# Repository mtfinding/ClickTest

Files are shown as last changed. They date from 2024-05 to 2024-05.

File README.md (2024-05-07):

# Automated Continuity Testing Device

## Overview

This repository contains the finalized source-code and hardware design documents of an automated hardware-tester. The projects was created as part of bachelor-thesis and is specifically designed for the Nucleo L432KC development board in combination with a propriatory harwdare expander used at my uni FHTW)  
## Features

- **Automated Continuity Testing**: The device automates the continuity testing process, reducing manual effort and increasing efficiency.
- **Terminal Interface**: A 115200baud UART terminal is available to visulaize test-results and select from certain testing-options.
- **Quick-Test Button**: A physical button that can be mapped to various test-actions via terminal commands.

## System overview

The system consists of a single PCBA project which can be broken apart in all necessary components with only little manual THT soldering required.
The main components are outlined in the image below.

hw_overview

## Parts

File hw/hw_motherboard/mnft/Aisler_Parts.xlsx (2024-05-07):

RefDes | Required MPN | MFR | Footprint | Comment
C101, C201, C301, C302, C401, C601, C603 | C0603C105M3PACTU | KEMET | 0603
C102, C202, C303, C304, C402, C501, C502, C602, C604 | 0603F104Z500CT | WALSIN | 0603
D501, D502, D503, D504 | 1N4148WS | SMC Diode Solutions | SOD323
D505 | 150060RS75000 | Wurth Electronics | 0603
D506, D507, D508 | 150060GS75000 | Wurth Electronics | 0603
R101, R201, R301, R302, R401, R501, R505, R507, R515, R601, R624 | RK73H1JRTTD1002F | KOA | 0603
R416, R417, R418, R419, R511, R512, R513, R514, R625, R626, R627, R628, R629, R630, R631, R632 | 0R Resistor - USE SMART MATCH | - | 0603
R102, R103, R104, R105, R106, R107, R108, R109, R110, R111, R112, R113, R114, R115, R116, R117, R202, R203, R204, R205, R206, R207, R208, R209, R210, R211, R212, R213, R214, R215, R216, R217, R303, R304, R305, R306, R307, R308, R309, R310, R311, R312, R313, R314, R315, R316, R317, R318, R319, R320, R321, R322, R323, R324, R325, R326, R327, R328, R329, R330, R331, R332, R402, R403, R404, R405, R406, R407, R408, R409, R410, R411, R412, R413, R414, R415, R602, R603, R604, R605, R606, R607, R608, R609, R610, R611, R612, R613, R615, R616, R617, R618, R619, R620, R621, R622, R623 | RK73B1ETTP221J | KOA | 0402 | 220 ohm used instead of 200 ohm due to availability
R502, R503, R504, R506 | RK73B1JTTD222J | KOA | 0603
R508, R509, R510, R516, R517 | RK73H1JRTTD1001F | KOA | 0603
U101, U201, U301, U302, U401, U601, U602 | TCA9555PWR | Texas Instruments | TSSOP-24
Set all other positions to „Exclude“

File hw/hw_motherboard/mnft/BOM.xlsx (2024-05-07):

Comment | Designator | Footprint | JLCPCB Part #（optional）
C_0603_100n | C102,C202,C303,C304,C402,C501,C502,C602,C604 | C_0603_1608Metric | C14663
C_0603_1u | C101,C201,C301,C302,C401,C601,C603 | C_0603_1608Metric | C15849
1N4148WS | D501,D502,D503,D504 | D_SOD-323F | C2128
LED_Green | D506,D507,D508 | LED_0603_1608Metric | C72043
LED_Red | D505 | LED_0603_1608Metric | C2286
SD05C.TCT | D101,D102,D103,D104,D105,D106,D107,D108,D109,D110,D111,D112,D113,D114,D115,D116,D201,D202,D203,D204,D205,D206,D207,D208,D209,D210,D211,D212,D213,D214,D215,D216,D301,D302,D303,D304,D305,D306,D307,D308,D309,D310,D311,D312,D313,D314,D315,D316,D317,D318,D319,D320,D321,D322,D323,D324,D325,D326,D327,D328,D329,D330,D401,D402,D403,D404,D405,D406,D407,D408,D409,D410,D411,D412,D413,D414,D601,D602,D603,D604,D605,D606,D607,D608,D609,D610,D611,D612,D613,D614,D615,D616,D617,D618,D619,D620 | D_SOD-323_HandSoldering | C85200
0R | R416,R417,R418,R419,R511,R512,R513,R514,R625,R626,R627,R628,R629,R630,R631,R632 | R_0603_1608Metric_Pad0.98x0.95mm_HandSolder | C21189
0R_DNI | R614,R633 | R_0603_1608Metric_Pad0.98x0.95mm_HandSolder | C21189
R_0402_200 | R102,R103,R104,R105,R106,R107,R108,R109,R110,R111,R112,R113,R114,R115,R116,R117,R202,R203,R204,R205,R206,R207,R208,R209,R210,R211,R212,R213,R214,R215,R216,R217,R303,R304,R305,R306,R307,R308,R309,R310,R311,R312,R313,R314,R315,R316,R317,R318,R319,R320,R321,R322,R323,R324,R325,R326,R327,R328,R329,R330,R331,R332,R402,R403,R404,R405,R406,R407,R408,R409,R410,R411,R412,R413,R414,R415,R602,R603,R604,R605,R606,R607,R608,R609,R610,R611,R612,R613,R615,R616,R617,R618,R619,R620,R621,R622,R623 | R_0402_1005Metric | C25087
R_0603_10k | R101,R201,R301,R302,R401,R501,R505,R507,R515,R601,R624 | R_0603_1608Metric | C25804
R_0603_1k | R508,R509,R510,R516,R517 | R_0603_1608Metric | C21190
R_0603_2.2k | R502,R503,R504,R506 | R_0603_1608Metric | C4190
TCA9555PWR | U101, U201, U301, U302, U401, U601, U602 | TSSOP-24_4.4x7.8mm_P0.65mm | C465732

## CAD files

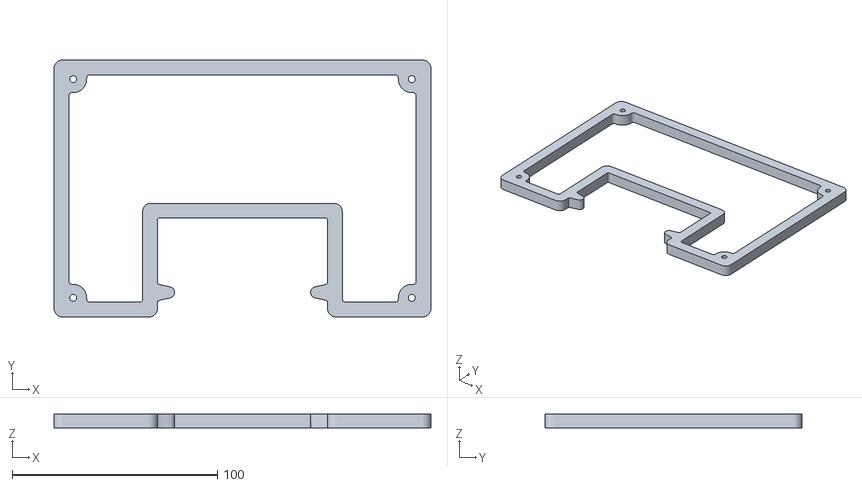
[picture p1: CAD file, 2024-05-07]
hw/mount/bac_hw_motherboard_mount_v1.stl
183.8 x 125.4 x 7.00

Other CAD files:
hw/mount/bac_hw_motherboard_mount_v1.f3d

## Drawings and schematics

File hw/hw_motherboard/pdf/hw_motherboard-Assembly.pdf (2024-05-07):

+ ERROR ⁺ | +

5V +

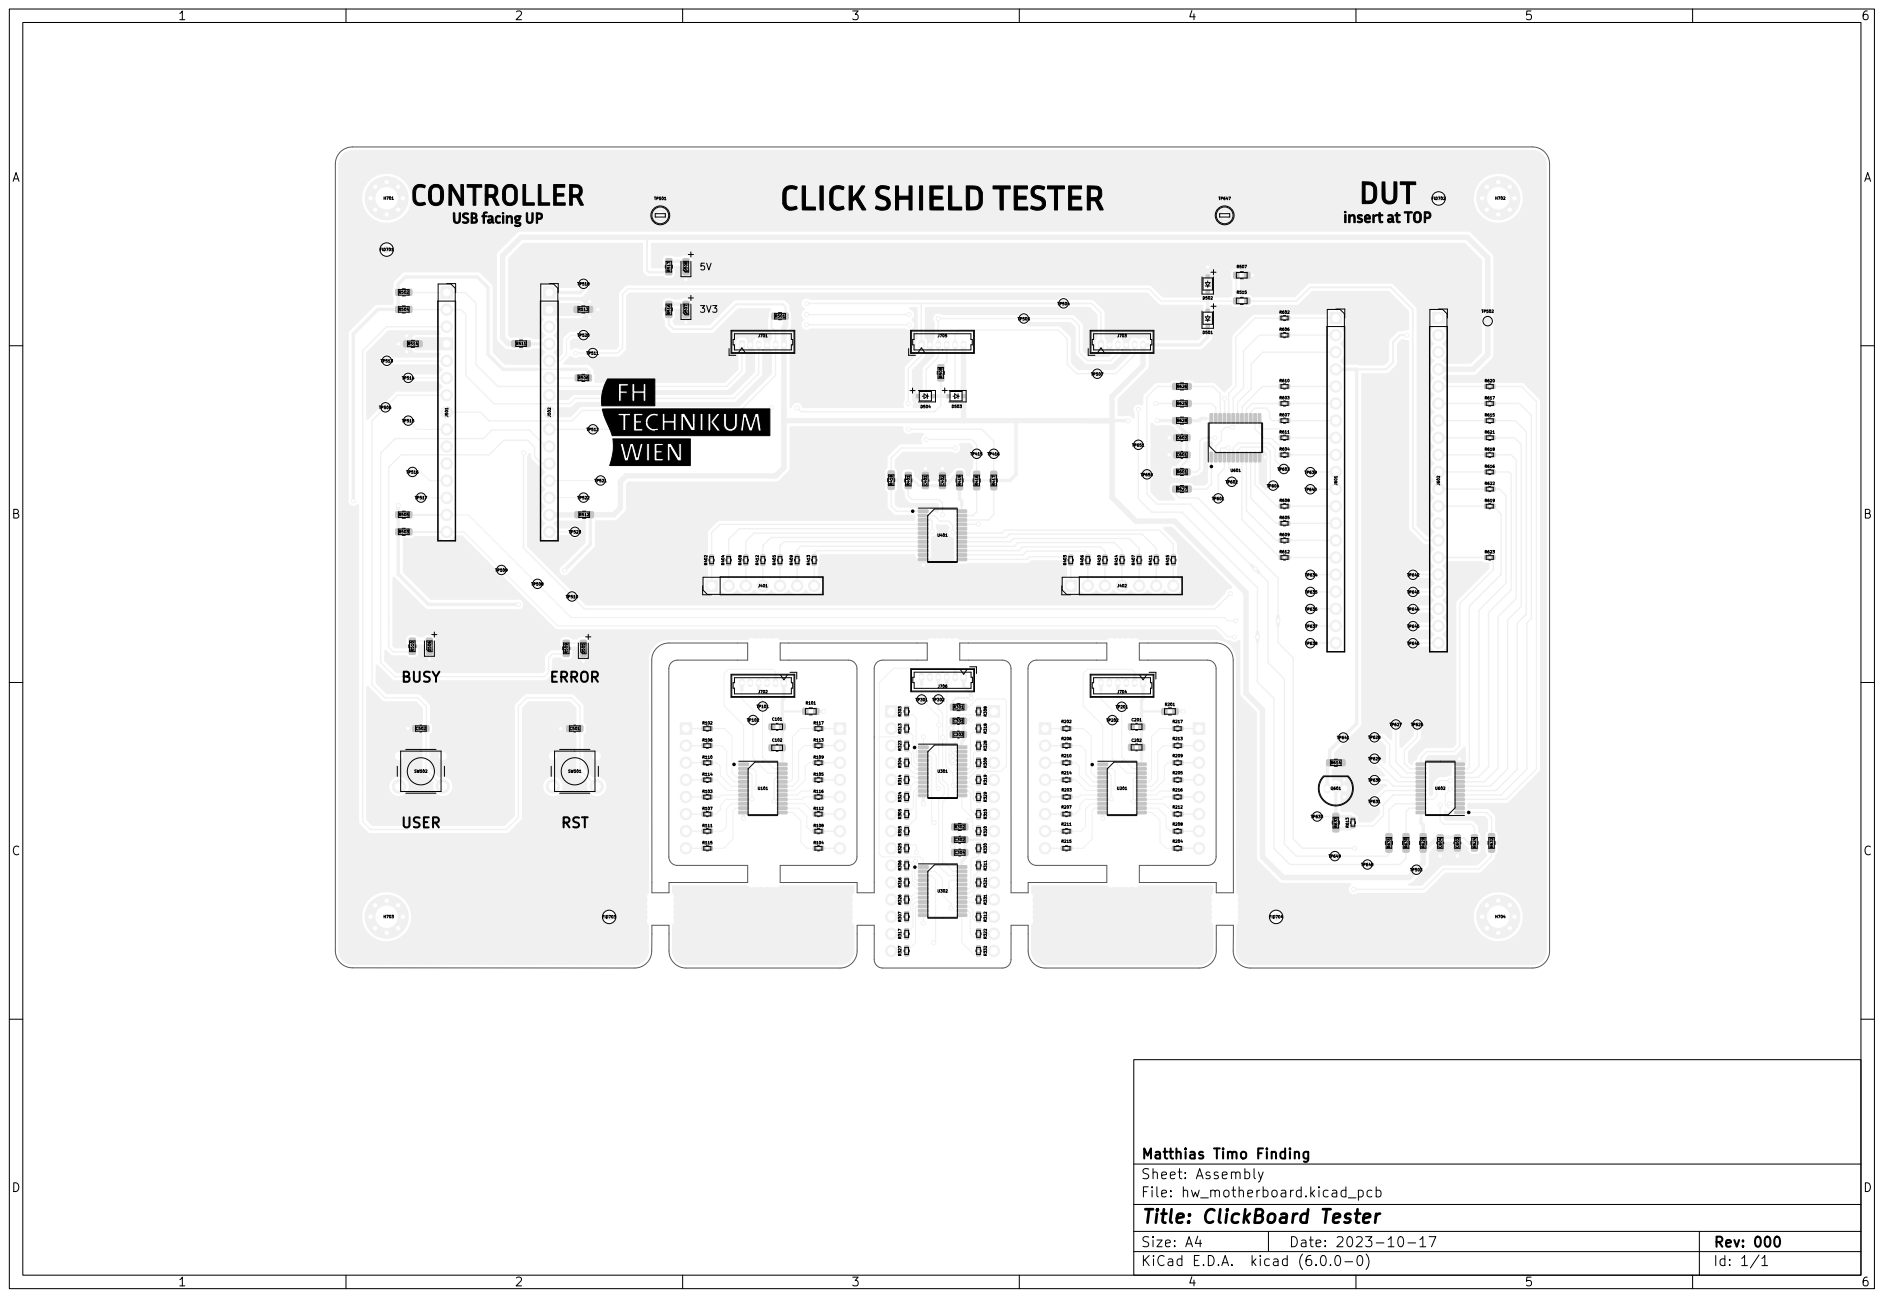
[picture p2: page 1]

Sheet: Assembly
File: hw_motherboard.kicad_pcb
Id: 1/1 Title: ClickBoard Tester

1 | 2 | 3 | 4 | 5 | 6

A

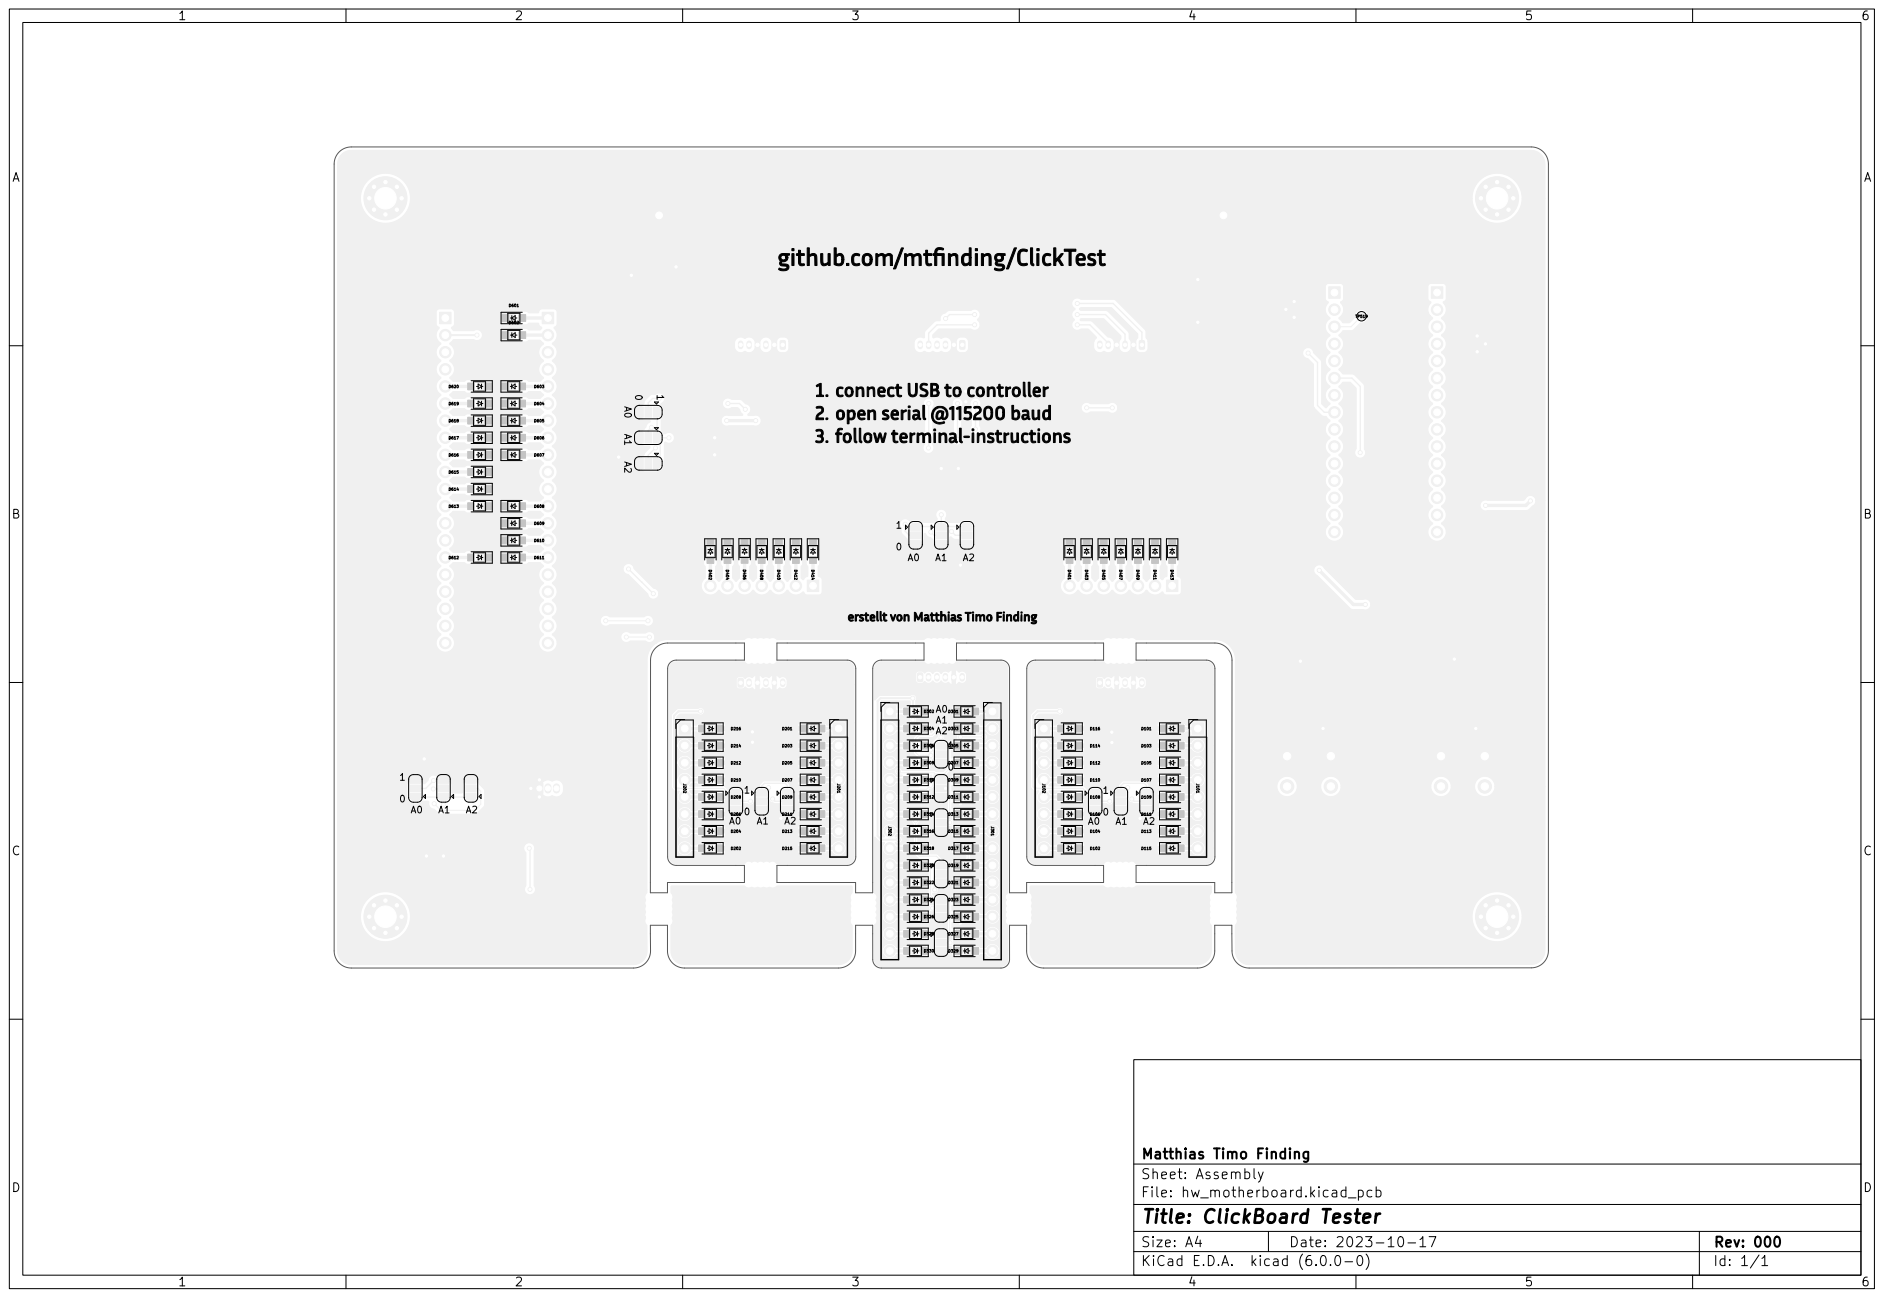
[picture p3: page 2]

Matthias Timo Finding
Sheet: Assembly
File: hw_motherboard.kicad_pcb
Id: 1/1 Title: ClickBoard Tester

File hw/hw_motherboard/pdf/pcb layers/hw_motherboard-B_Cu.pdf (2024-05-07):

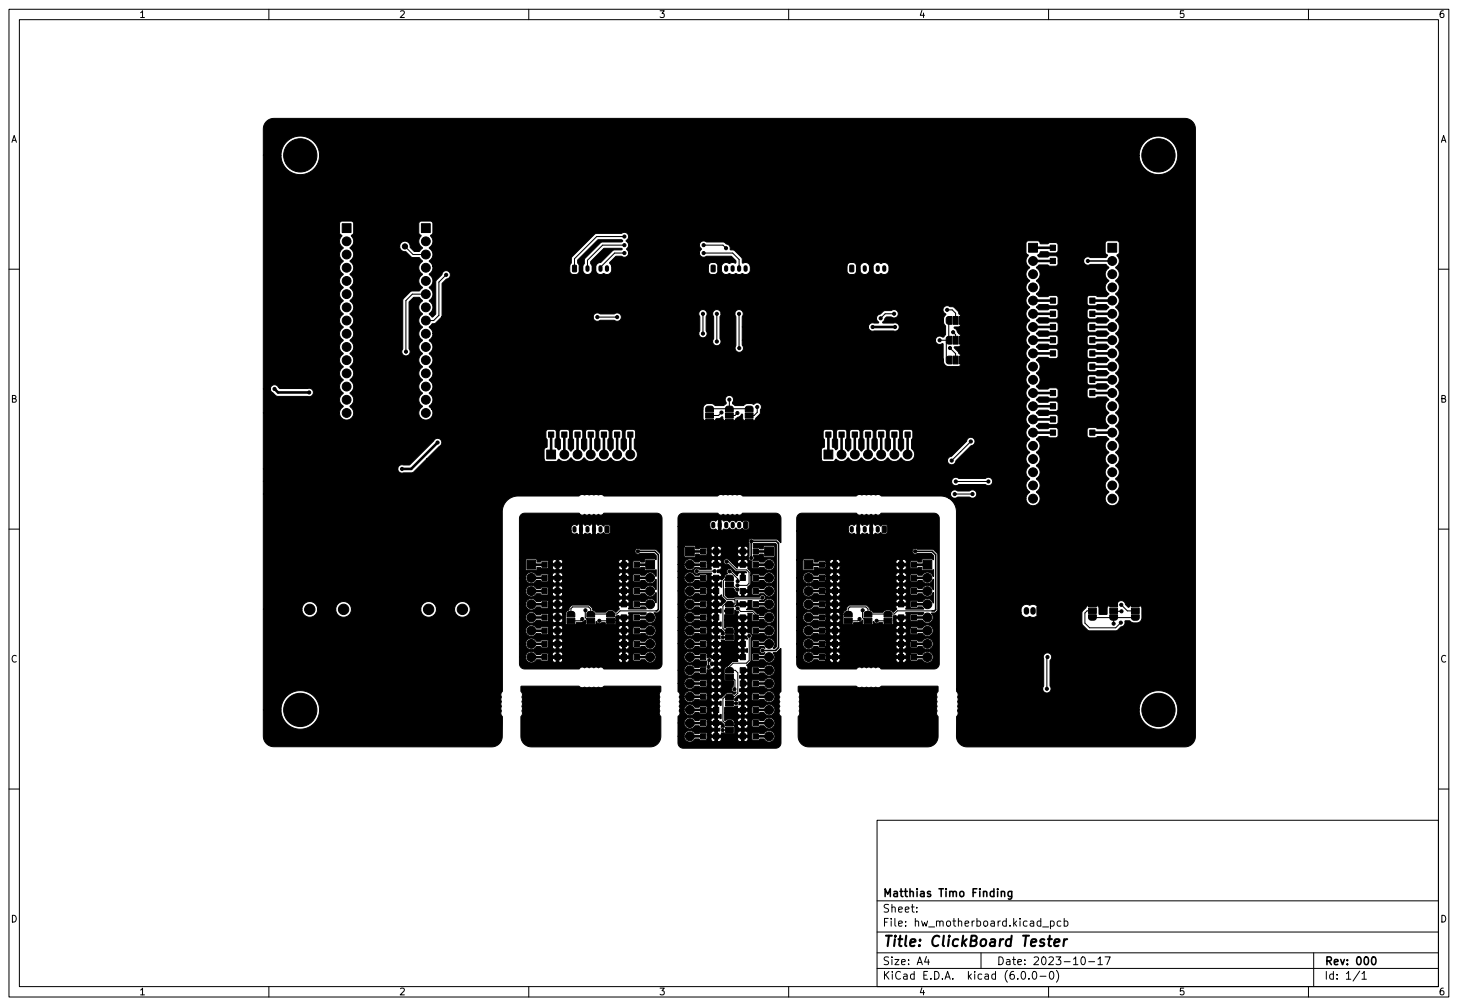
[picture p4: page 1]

File: hw_motherboard.kicad_pcb Sheet: Matthias Timo Finding

Id: 1/1 Title: ClickBoard Tester

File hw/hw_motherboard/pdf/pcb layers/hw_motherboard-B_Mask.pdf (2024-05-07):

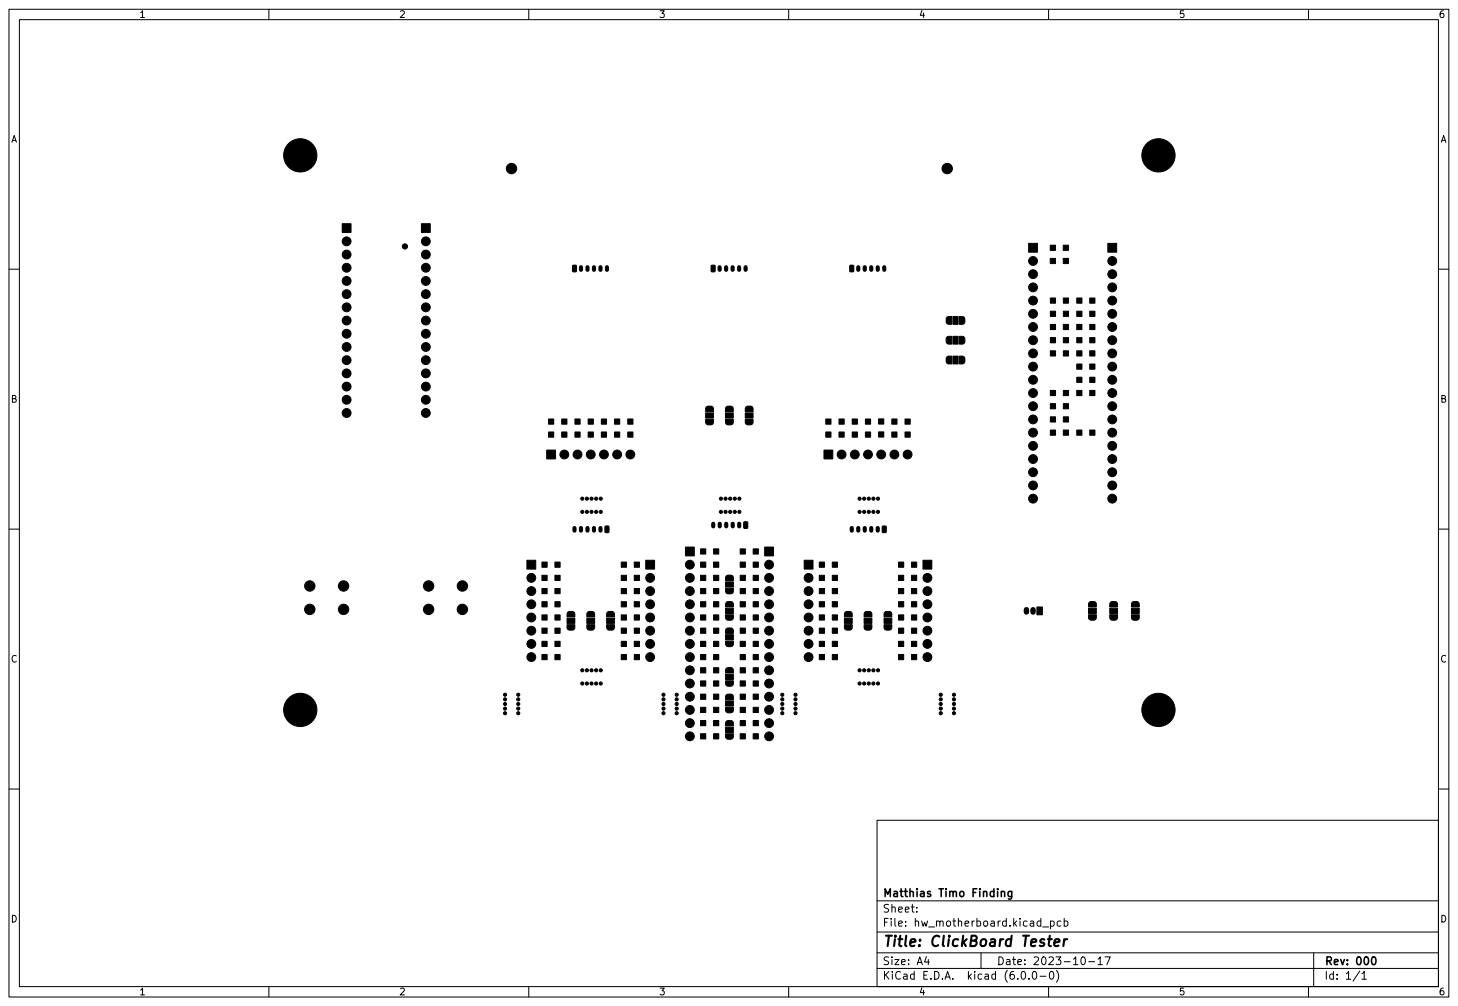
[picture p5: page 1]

File: hw_motherboard.kicad_pcb Sheet: Matthias Timo Finding

Id: 1/1 Title: ClickBoard Tester

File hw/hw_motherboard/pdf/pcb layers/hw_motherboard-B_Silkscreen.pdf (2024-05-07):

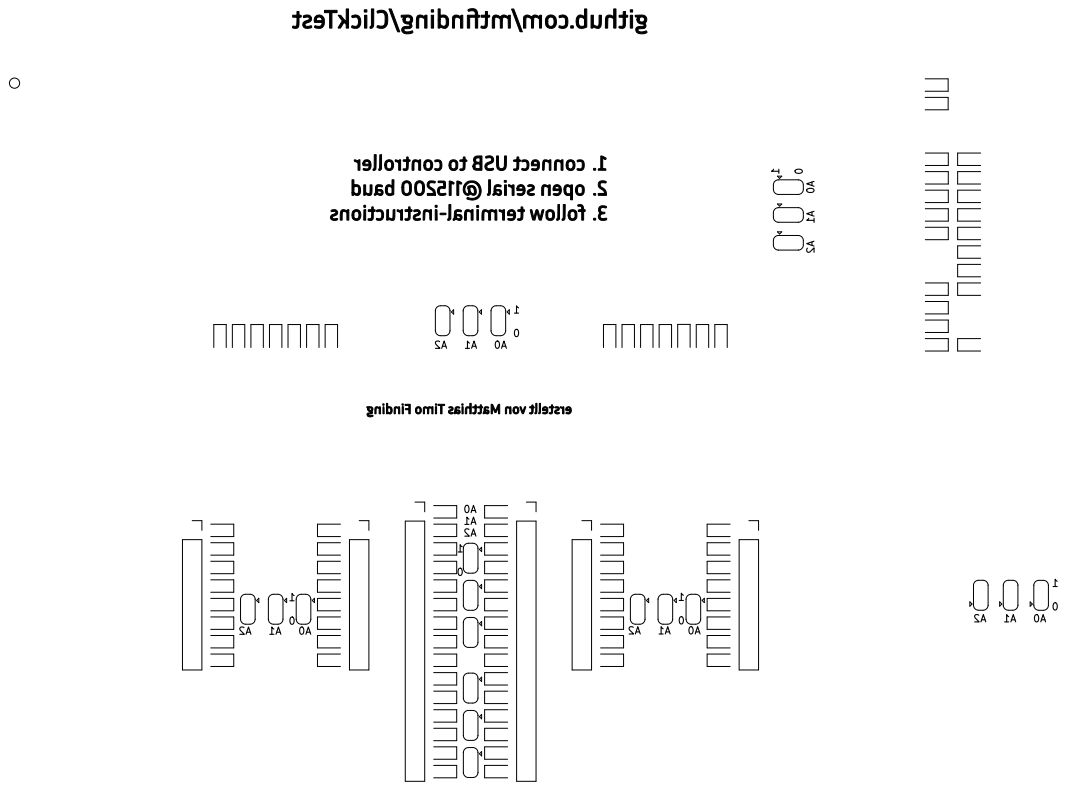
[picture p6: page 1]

File: hw_motherboard.kicad_pcb Sheet: Matthias Timo Finding

Id: 1/1 Title: ClickBoard Tester

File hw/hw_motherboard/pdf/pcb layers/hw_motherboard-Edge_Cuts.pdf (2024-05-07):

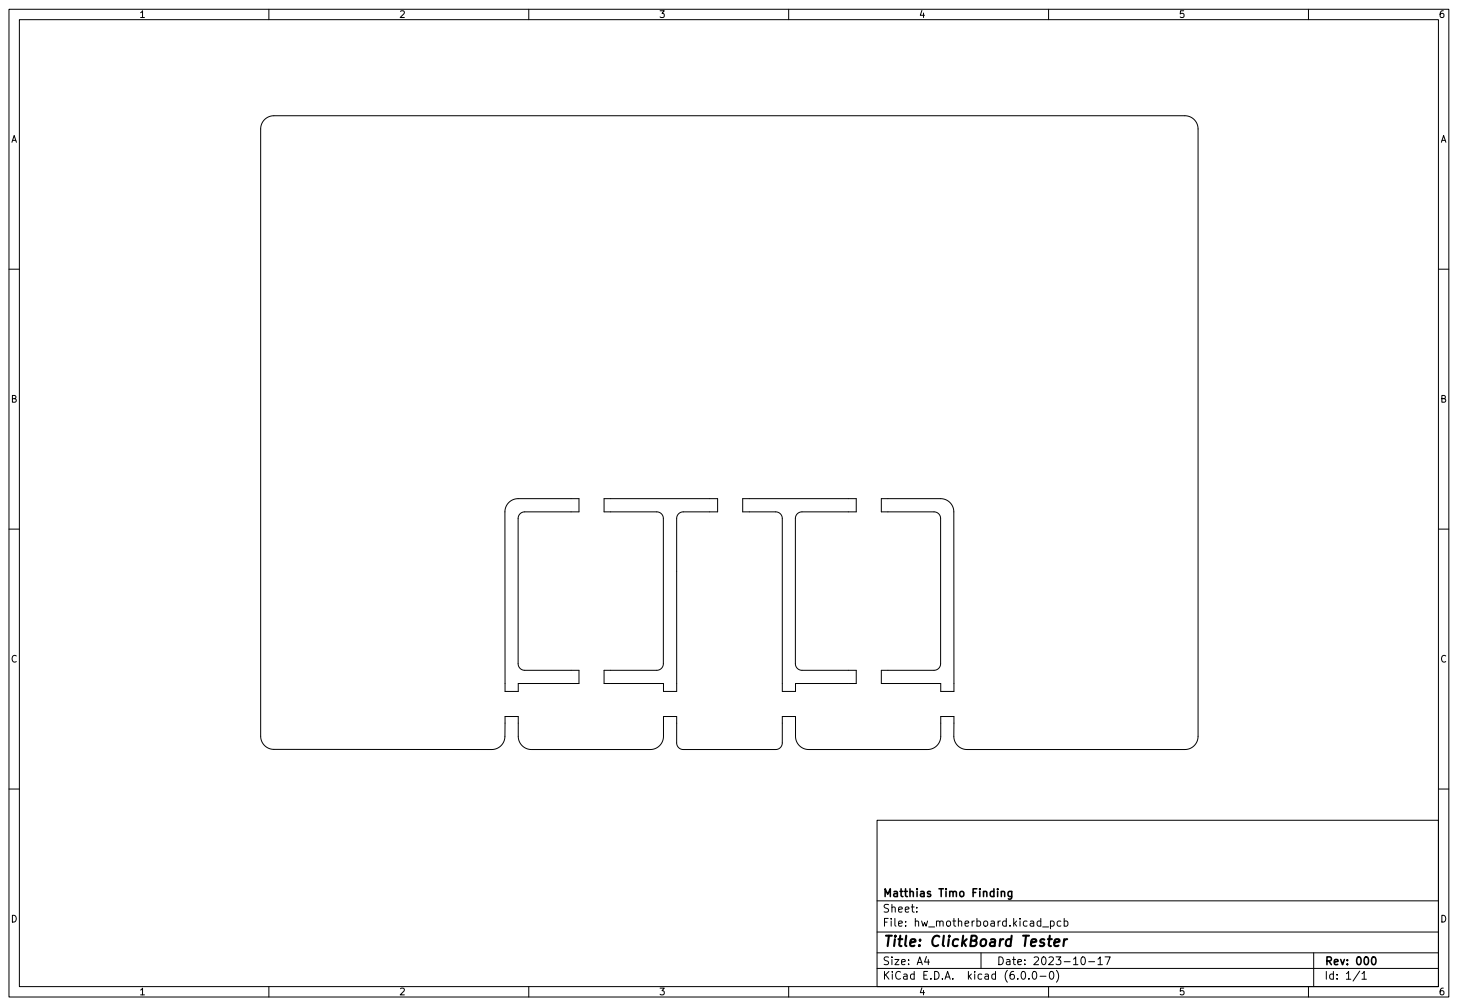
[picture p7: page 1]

File: hw_motherboard.kicad_pcb Sheet: Matthias Timo Finding

Id: 1/1 Title: ClickBoard Tester

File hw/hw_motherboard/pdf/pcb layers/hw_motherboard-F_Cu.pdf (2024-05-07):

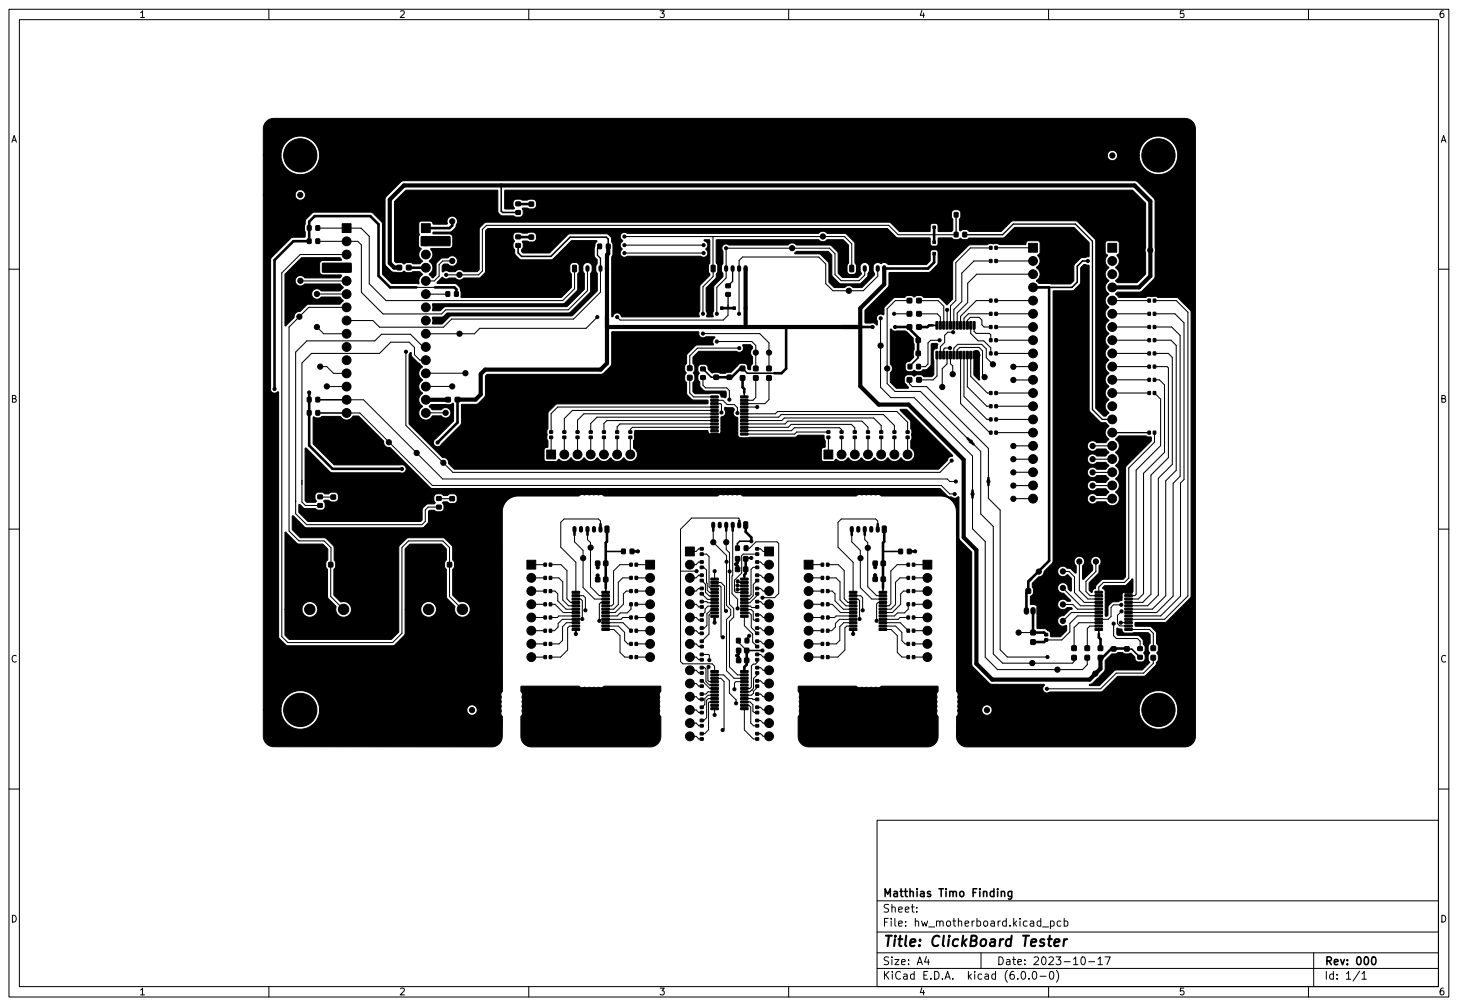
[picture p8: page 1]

File: hw_motherboard.kicad_pcb Sheet: Matthias Timo Finding

Id: 1/1 Title: ClickBoard Tester

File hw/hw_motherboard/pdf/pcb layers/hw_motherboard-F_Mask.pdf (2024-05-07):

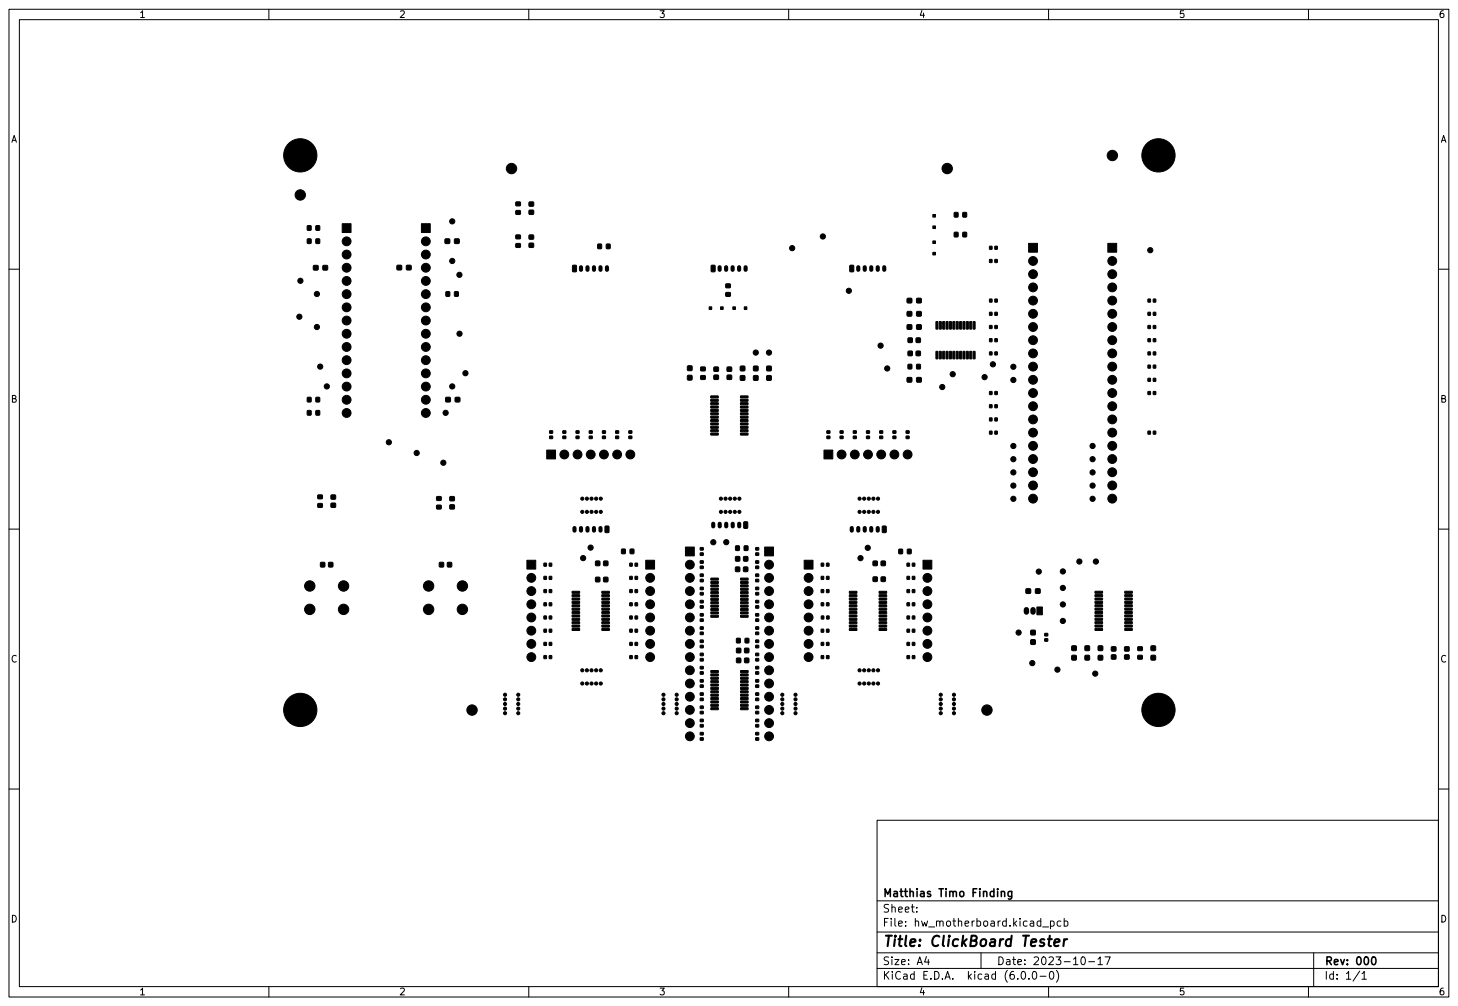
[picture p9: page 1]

File: hw_motherboard.kicad_pcb Sheet: Matthias Timo Finding

Id: 1/1 Title: ClickBoard Tester

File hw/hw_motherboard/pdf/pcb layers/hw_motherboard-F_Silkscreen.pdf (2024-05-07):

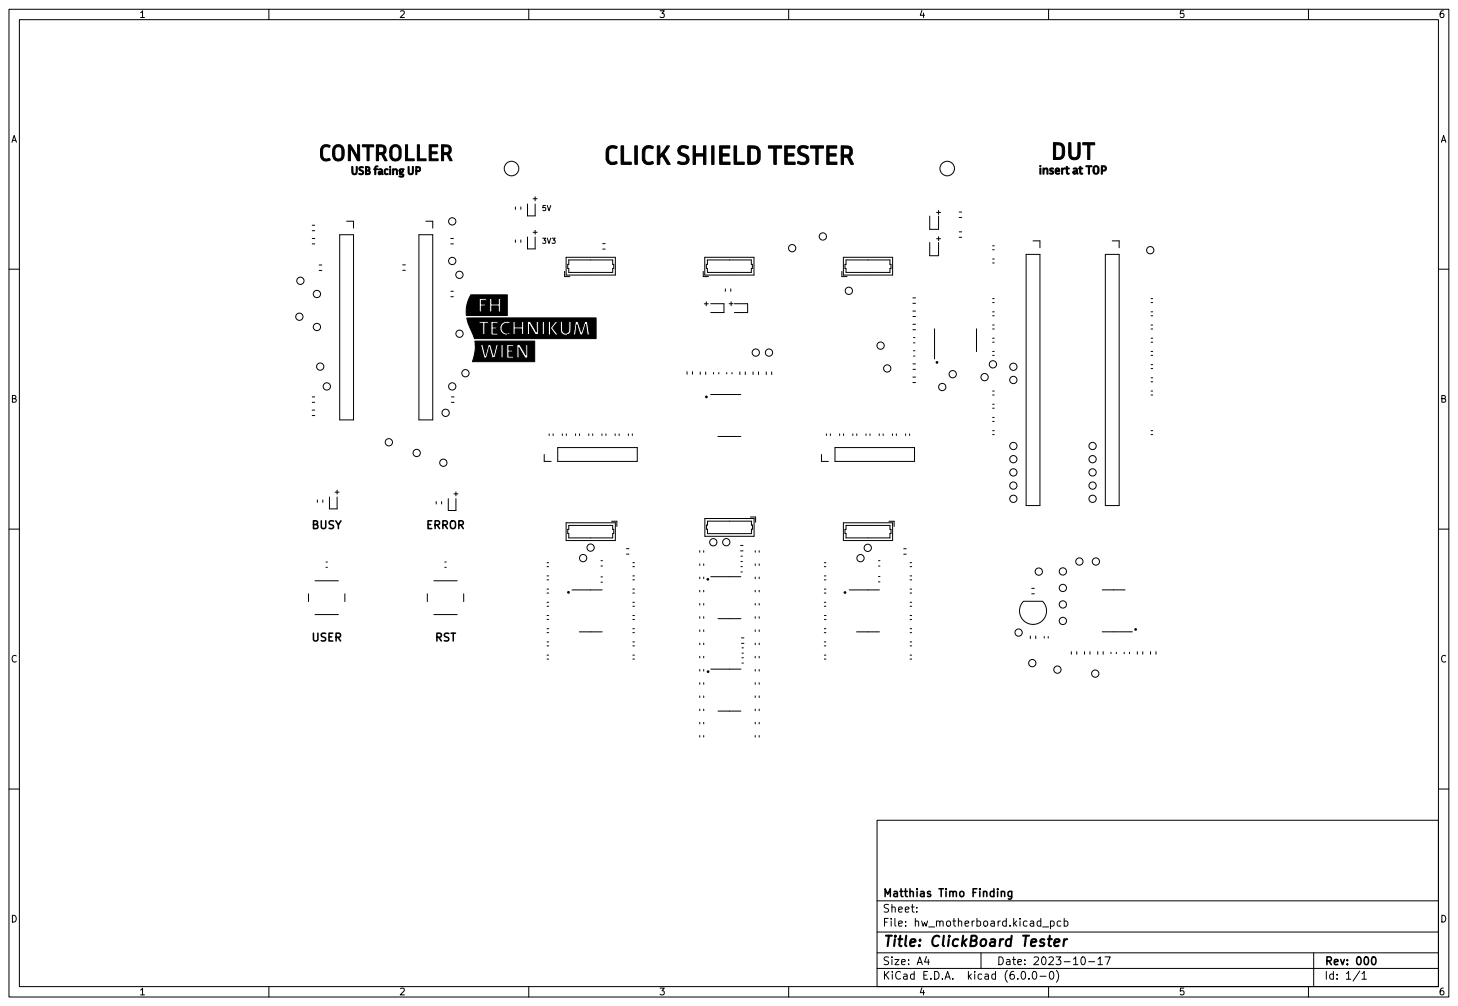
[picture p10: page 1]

File: hw_motherboard.kicad_pcb Sheet: Matthias Timo Finding

Id: 1/1 Title: ClickBoard Tester

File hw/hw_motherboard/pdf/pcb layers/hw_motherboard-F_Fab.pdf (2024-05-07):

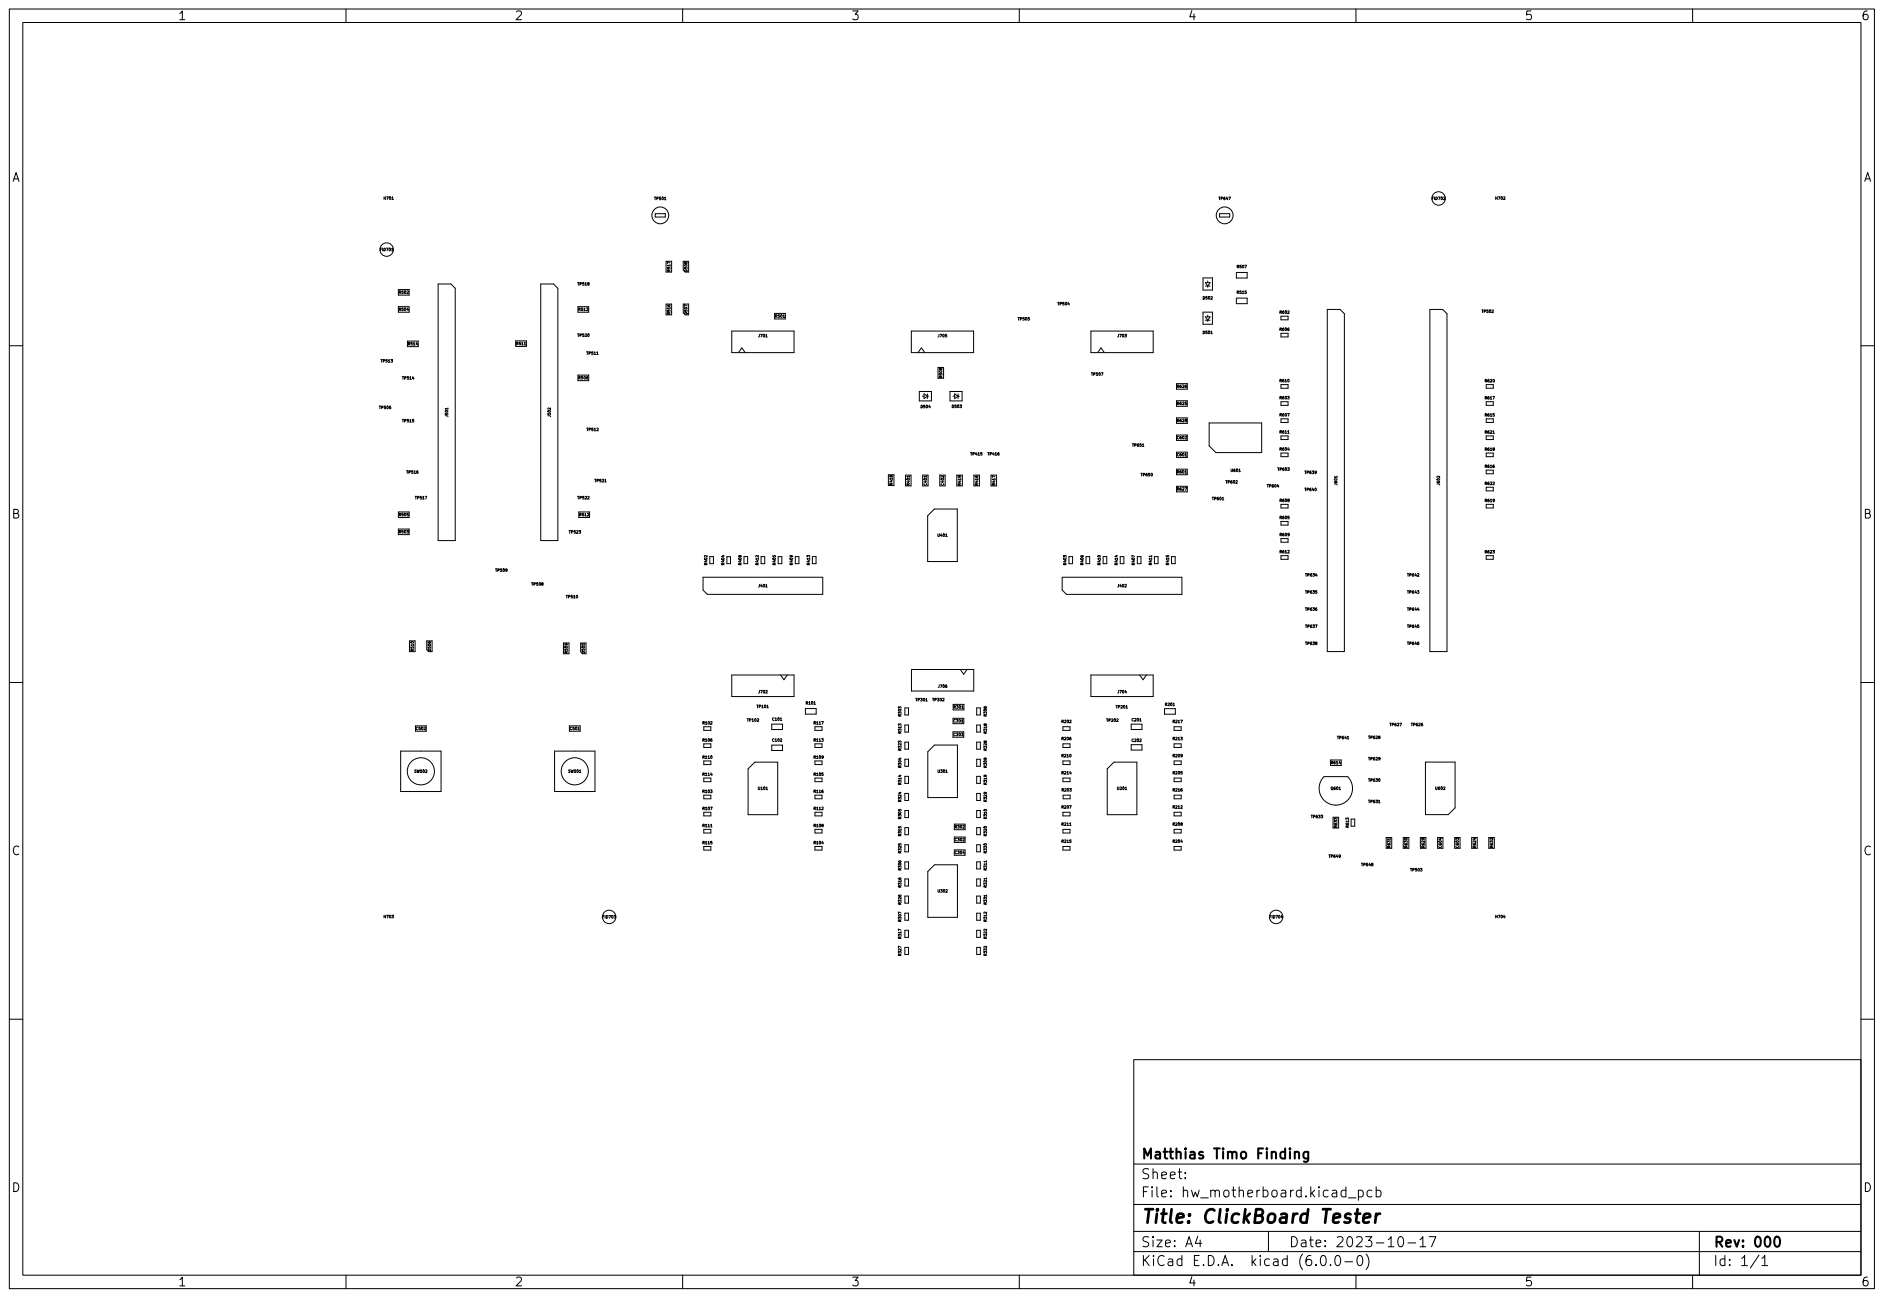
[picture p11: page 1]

Id: 1/1 Title: ClickBoard Tester

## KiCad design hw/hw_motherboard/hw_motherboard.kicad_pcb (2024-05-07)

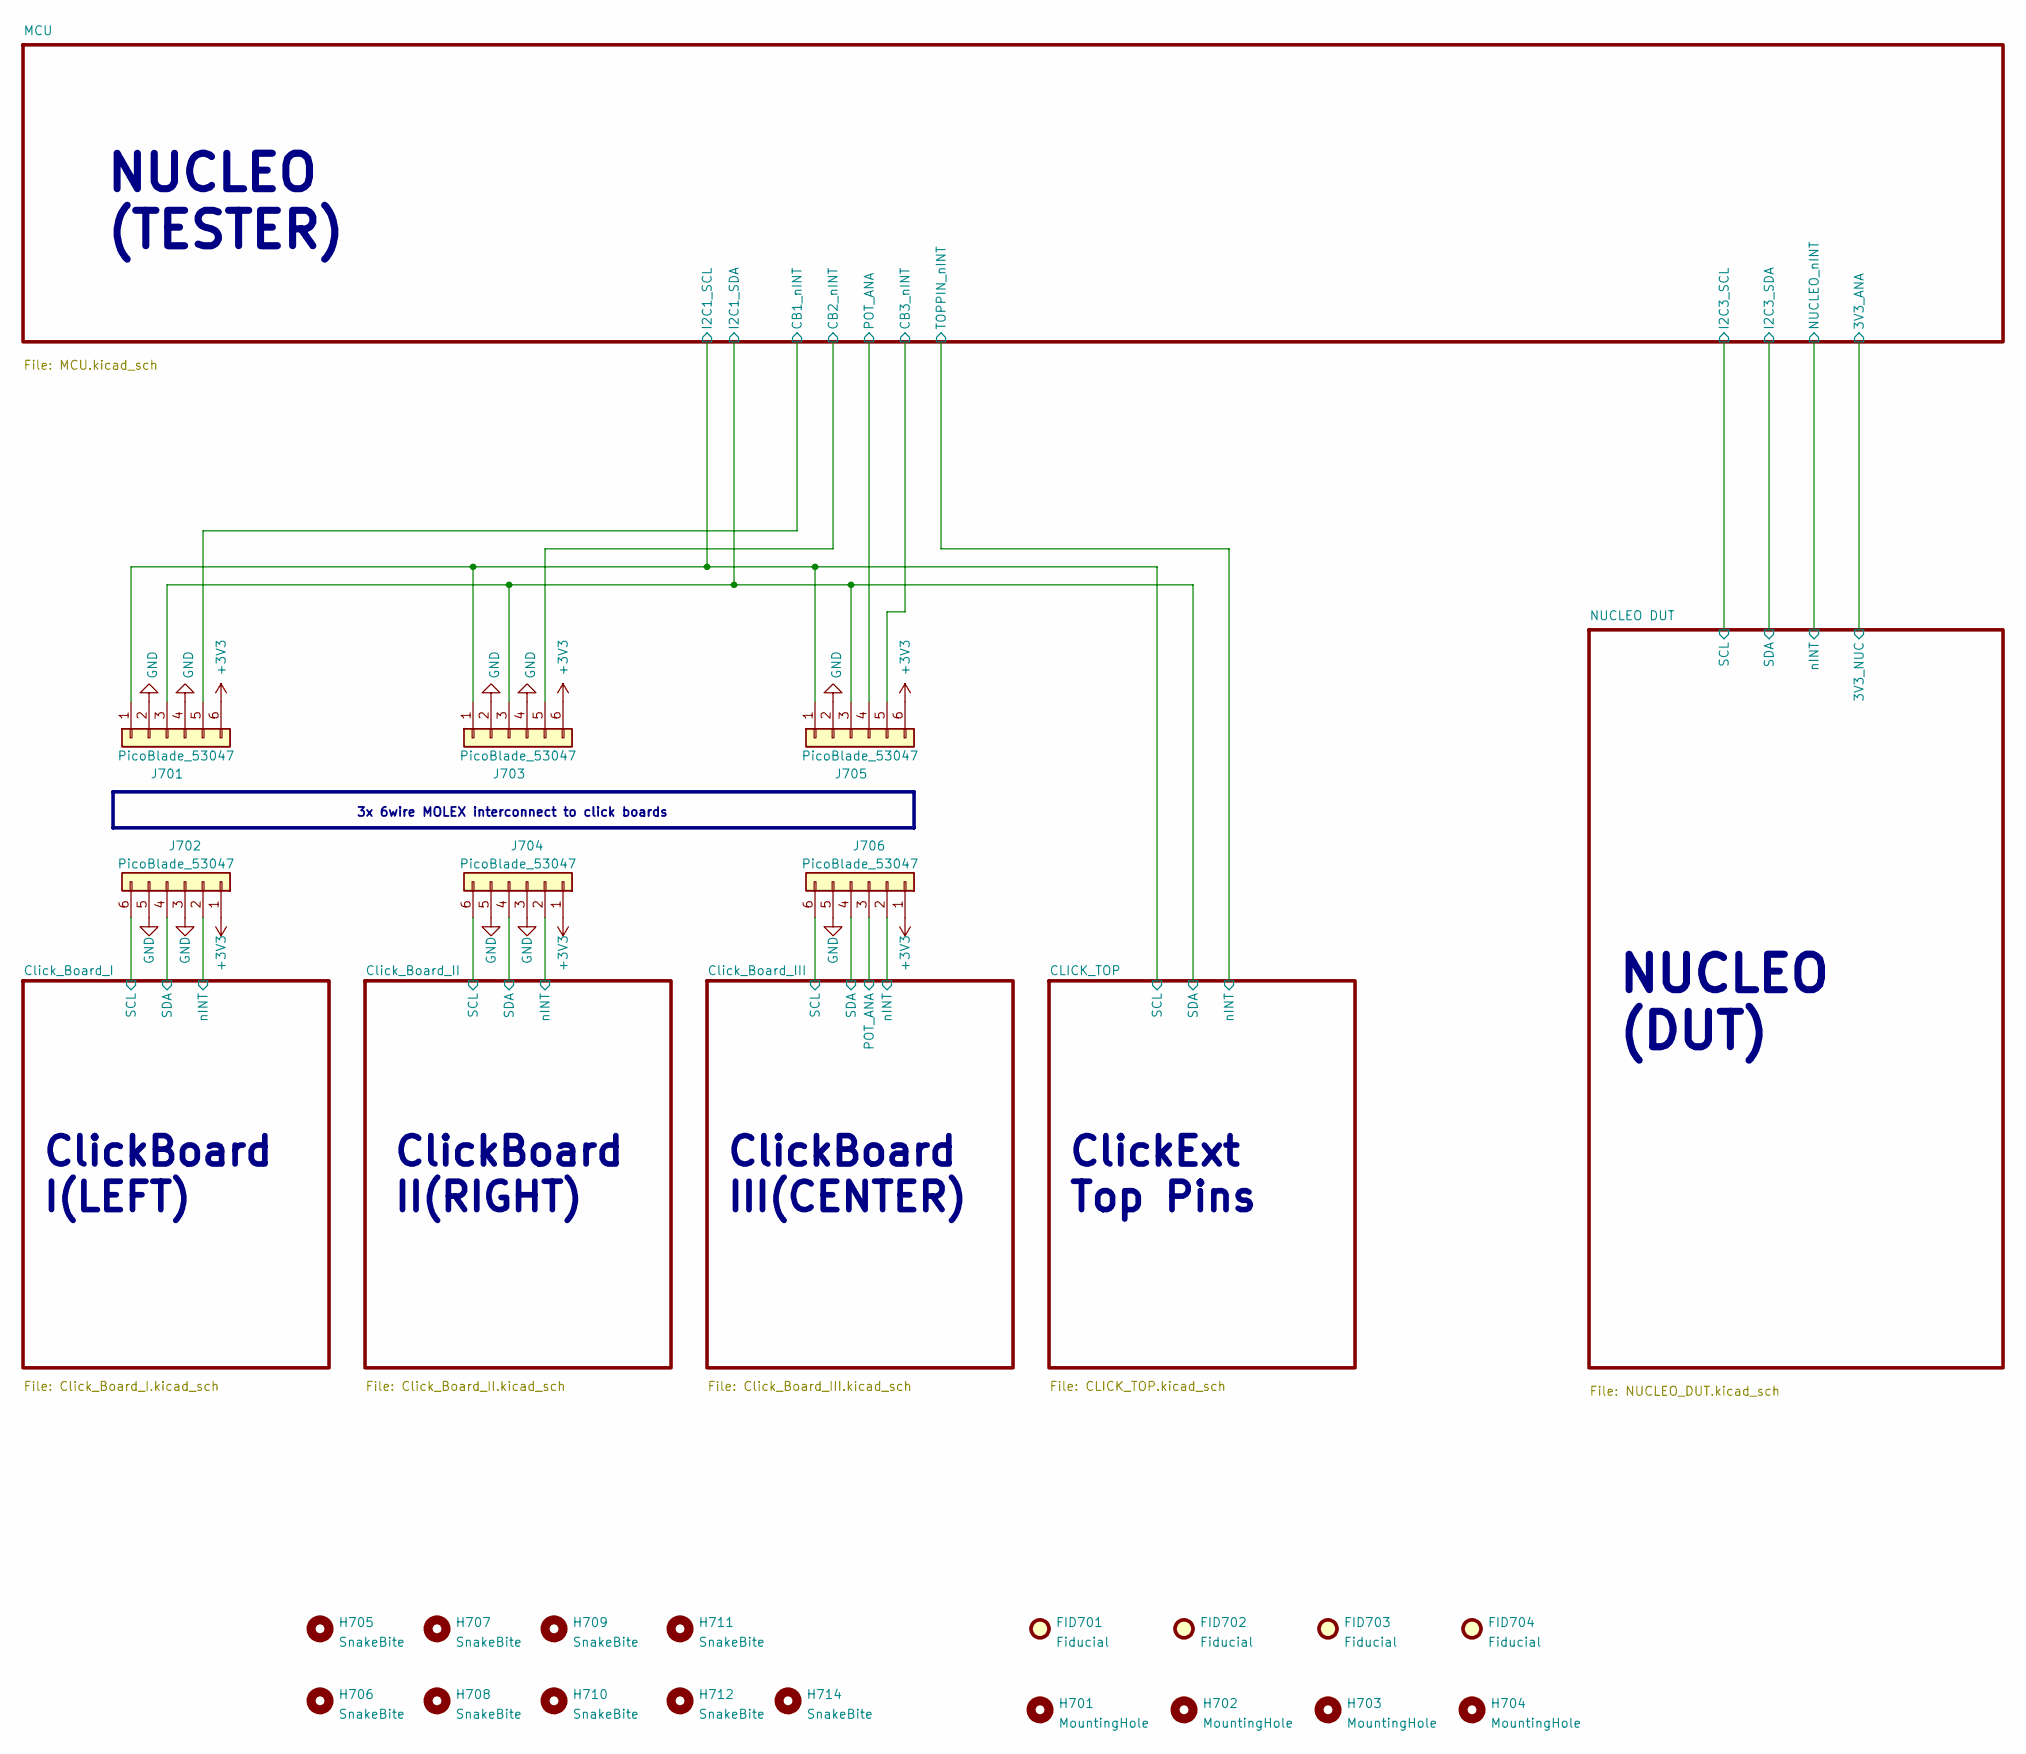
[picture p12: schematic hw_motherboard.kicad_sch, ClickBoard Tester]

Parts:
FID701, FID702, FID703, FID704: Fiducial; Fiducial_1mm_Mask2mm
H701, H702, H703, H704: MountingHole; MountingHole_3.2mm_M3_Pad_Via
H705, H706, H707, H708, H709, H710, H711, H712, H714: SnakeBite; JLC_SnakeBite_1.27mm
J701, J702, J703, J704, J705, J706: PicoBlade_53047; Molex_PicoBlade_53047-0610_1x06_P1.25mm_Vertical

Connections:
+3V3: J701.6, J702.1, J703.6, J704.1, J705.6, J706.1; also elsewhere on the board
/Click_Board_I/SCL: J702.6; also elsewhere on the board
/Click_Board_I/SDA: J702.4; also elsewhere on the board
/Click_Board_I/nINT: J702.2; also elsewhere on the board
/Click_Board_II/SCL: J704.6; also elsewhere on the board
/Click_Board_II/SDA: J704.4; also elsewhere on the board
/Click_Board_II/nINT: J704.2; also elsewhere on the board
/Click_Board_III/POT_ANA: J706.3; also elsewhere on the board
/Click_Board_III/SCL: J706.6; also elsewhere on the board
/Click_Board_III/SDA: J706.4; also elsewhere on the board
/Click_Board_III/nINT: J706.2; also elsewhere on the board
/MCU/MCU_PA9: J701.1, J703.1, J705.1; also elsewhere on the board
/MCU/MCU_PA10: J701.3, J703.3, J705.3; also elsewhere on the board
/MCU/MCU_PB6: J701.5, J703.5, J705.5; also elsewhere on the board
/MCU/POT_ANA: J705.4; also elsewhere on the board
GND: J701.2, J701.4, J702.3, J702.5, J703.2, J703.4, J704.3, J704.5, J705.2, J706.5; also elsewhere on the board

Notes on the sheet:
3x 6wire MOLEX interconnect to click boards
NUCLEO (DUT)
ClickBoard I(LEFT)
ClickExt Top Pins
ClickBoard III(CENTER)
NUCLEO (TESTER)
ClickBoard II(RIGHT)

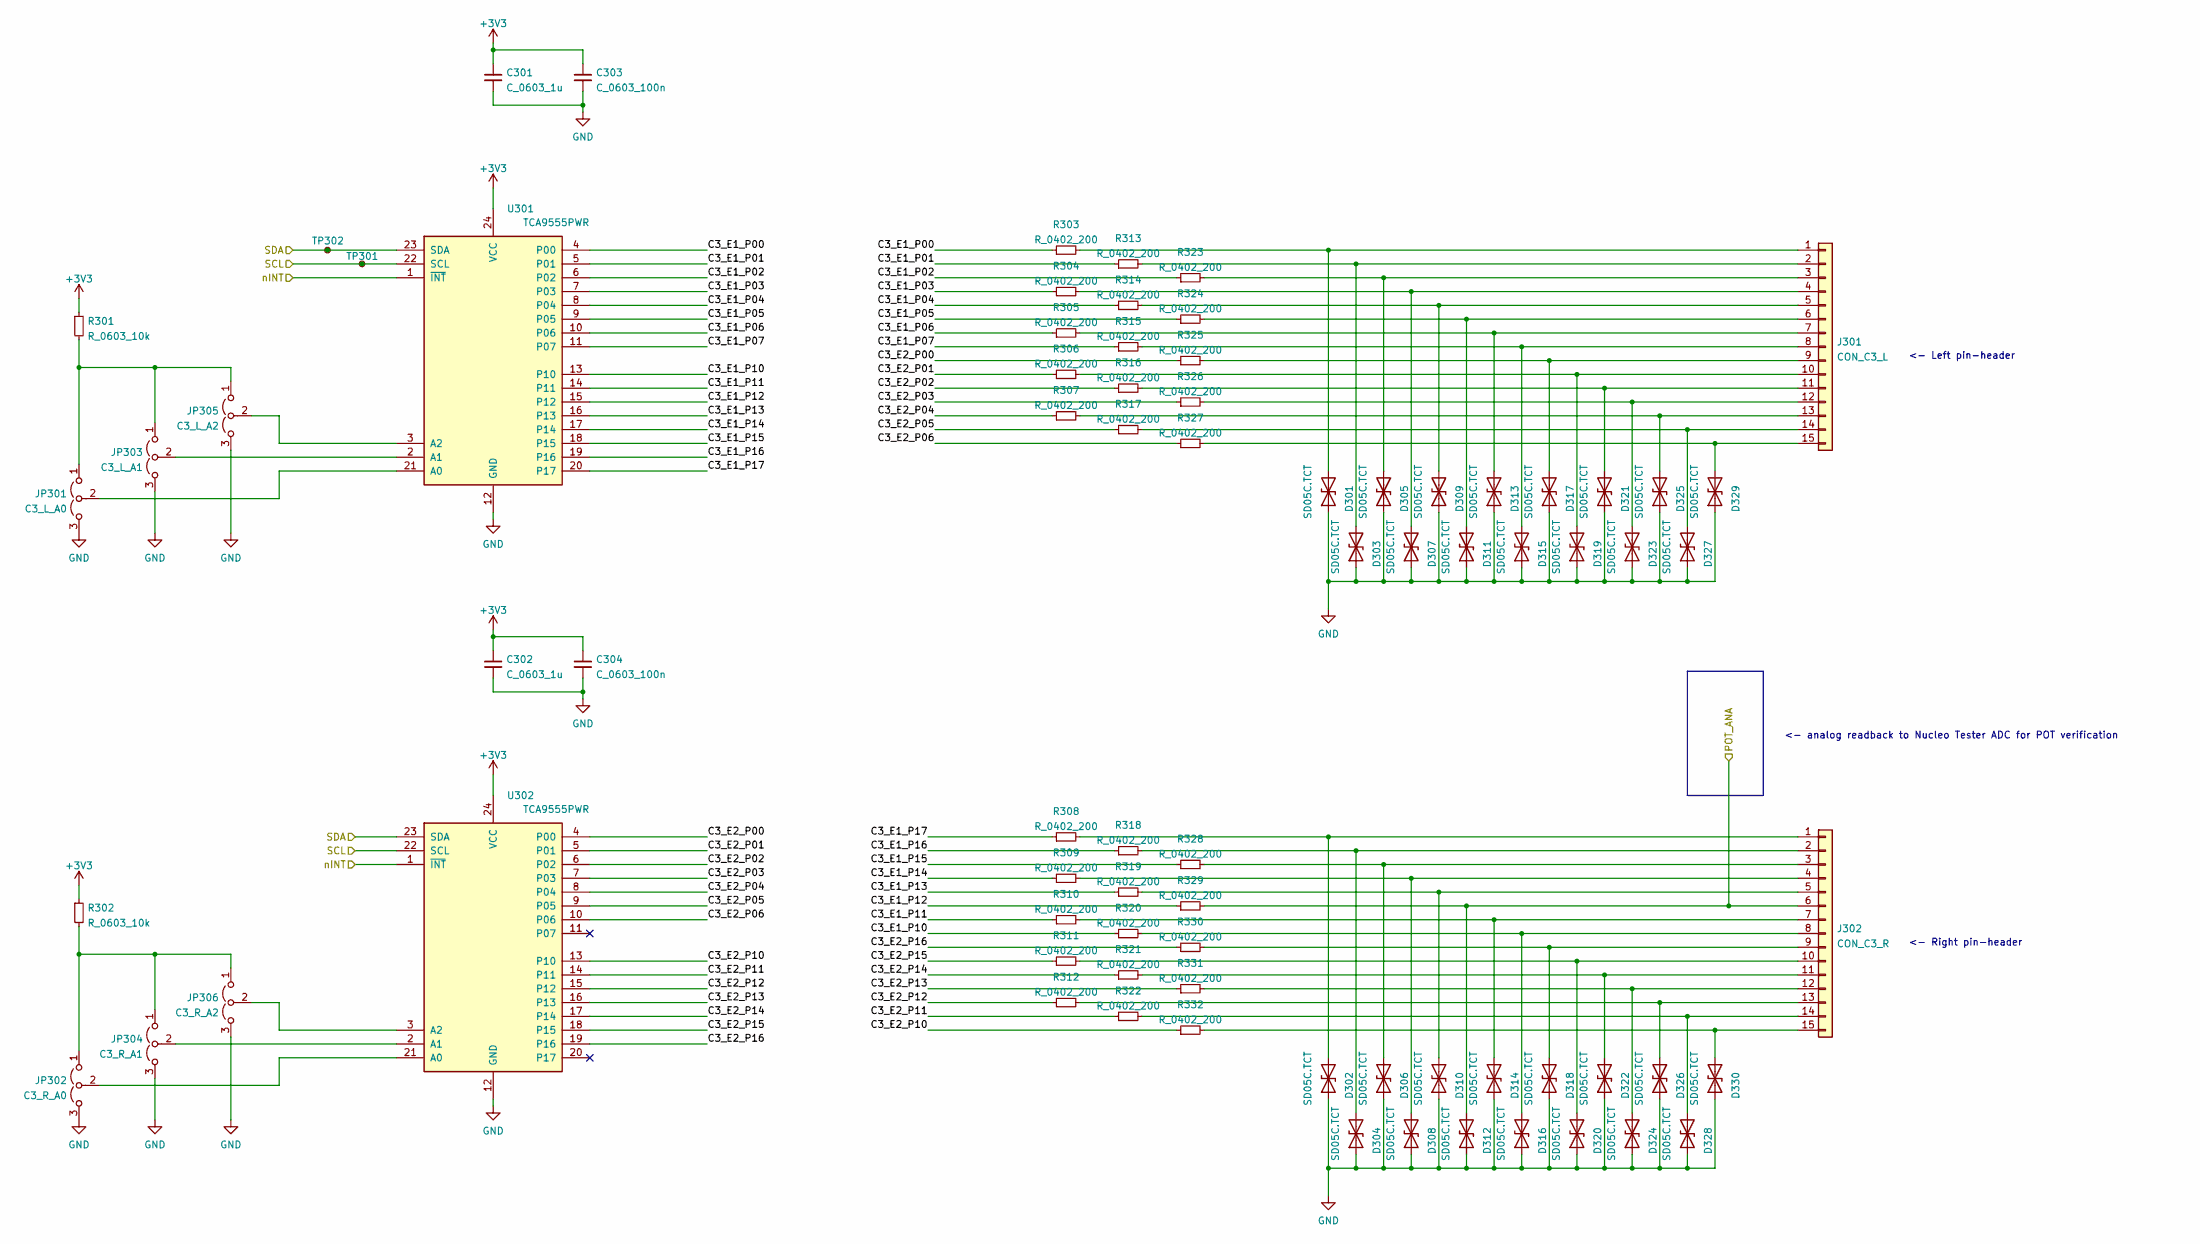
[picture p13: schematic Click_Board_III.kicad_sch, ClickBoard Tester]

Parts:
C301, C302: C_0603_1u; C_0603_1608Metric; LCSC Part # C15849
C303, C304: C_0603_100n; C_0603_1608Metric; LCSC Part # C14663
D301, D302, D303, D304, D305, D306, D307, D308, D309, D310, D311, D312, D313, D314, D315, D316, D317, D318, D319, D320, D321, D322, D323, D324, D325, D326, D327, D328, D329, D330: SD05C.TCT; D_SOD-323_HandSoldering; LCSC Part # C85200
J301: CON_C3_L; PinHeader_1x15_P2.54mm_Vertical
J302: CON_C3_R; PinHeader_1x15_P2.54mm_Vertical
JP301: C3_L_A0; SolderJumper-3_P1.3mm_Open_RoundedPad1.0x1.5mm
JP302: C3_R_A0; SolderJumper-3_P1.3mm_Open_RoundedPad1.0x1.5mm
JP303: C3_L_A1; SolderJumper-3_P1.3mm_Open_RoundedPad1.0x1.5mm
JP304: C3_R_A1; SolderJumper-3_P1.3mm_Open_RoundedPad1.0x1.5mm
JP305: C3_L_A2; SolderJumper-3_P1.3mm_Open_RoundedPad1.0x1.5mm
JP306: C3_R_A2; SolderJumper-3_P1.3mm_Open_RoundedPad1.0x1.5mm
R301, R302: R_0603_10k; R_0603_1608Metric; LCSC Part # C25804
R303, R304, R305, R306, R307, R308, R309, R310, R311, R312, R313, R314, R315, R316, R317, R318, R319, R320, R321, R322, R323, R324, R325, R326, R327, R328, R329, R330, R331, R332: R_0402_200; R_0402_1005Metric; LCSC Part # C25087
TP301, TP302: TestPoint_Small; TestPoint_Pad_D1.0mm
U301, U302: TCA9555PWR; TSSOP-24_4.4x7.8mm_P0.65mm

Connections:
+3V3: C301.1, C302.1, C303.1, C304.1, R301.1, R302.1, U301.24 (VCC), U302.24 (VCC); also elsewhere on the board
/Click_Board_III/C3_E1_P00: R303.1, U301.4 (P00)
/Click_Board_III/C3_E1_P01: R313.1, U301.5 (P01)
/Click_Board_III/C3_E1_P02: R323.1, U301.6 (P02)
/Click_Board_III/C3_E1_P03: R304.1, U301.7 (P03)
/Click_Board_III/C3_E1_P04: R314.1, U301.8 (P04)
/Click_Board_III/C3_E1_P05: R324.1, U301.9 (P05)
/Click_Board_III/C3_E1_P06: R305.1, U301.10 (P06)
/Click_Board_III/C3_E1_P07: R315.1, U301.11 (P07)
/Click_Board_III/C3_E1_P10: R320.1, U301.13 (P10)
/Click_Board_III/C3_E1_P11: R310.1, U301.14 (P11)
/Click_Board_III/C3_E1_P12: R329.1, U301.15 (P12)
/Click_Board_III/C3_E1_P13: R319.1, U301.16 (P13)
/Click_Board_III/C3_E1_P14: R309.1, U301.17 (P14)
/Click_Board_III/C3_E1_P15: R328.1, U301.18 (P15)
/Click_Board_III/C3_E1_P16: R318.1, U301.19 (P16)
/Click_Board_III/C3_E1_P17: R308.1, U301.20 (P17)
/Click_Board_III/C3_E2_P00: R325.1, U302.4 (P00)
/Click_Board_III/C3_E2_P01: R306.1, U302.5 (P01)
/Click_Board_III/C3_E2_P02: R316.1, U302.6 (P02)
/Click_Board_III/C3_E2_P03: R326.1, U302.7 (P03)
/Click_Board_III/C3_E2_P04: R307.1, U302.8 (P04)
/Click_Board_III/C3_E2_P05: R317.1, U302.9 (P05)
/Click_Board_III/C3_E2_P06: R327.1, U302.10 (P06)
/Click_Board_III/C3_E2_P10: R332.1, U302.13 (P10)
/Click_Board_III/C3_E2_P11: R322.1, U302.14 (P11)
/Click_Board_III/C3_E2_P12: R312.1, U302.15 (P12)
/Click_Board_III/C3_E2_P13: R331.1, U302.16 (P13)
/Click_Board_III/C3_E2_P14: R321.1, U302.17 (P14)
/Click_Board_III/C3_E2_P15: R311.1, U302.18 (P15)
/Click_Board_III/C3_E2_P16: R330.1, U302.19 (P16)
/Click_Board_III/POT_ANA: D312.2 (A2), J302.6, R329.2; also elsewhere on the board
/Click_Board_III/SCL: TP301.1, U301.22 (SCL), U302.22 (SCL); also elsewhere on the board
/Click_Board_III/SDA: TP302.1, U301.23 (SDA), U302.23 (SDA); also elsewhere on the board
/Click_Board_III/nINT: U301.1 (~INT), U302.1 (~INT); also elsewhere on the board
GND: C301.2, C302.2, C303.2, C304.2, D301.1 (A1), D302.1 (A1), D303.1 (A1), D304.1 (A1), D305.1 (A1), D306.1 (A1), D307.1 (A1), D308.1 (A1), D309.1 (A1), D310.1 (A1), D311.1 (A1), D312.1 (A1), D313.1 (A1), D314.1 (A1), D315.1 (A1), D316.1 (A1), D317.1 (A1), D318.1 (A1), D319.1 (A1), D320.1 (A1), D321.1 (A1), D322.1 (A1), D323.1 (A1), D324.1 (A1), D325.1 (A1), D326.1 (A1), D327.1 (A1), D328.1 (A1), D329.1 (A1), D330.1 (A1), JP301.3 (B), JP302.3 (B), JP303.3 (B), JP304.3 (B), JP305.3 (B), JP306.3 (B), U301.12 (GND), U302.12 (GND); also elsewhere on the board
unnamed: D301.2 (A2), J301.1, R303.2
unnamed: D302.2 (A2), J302.1, R308.2
unnamed: D303.2 (A2), J301.2, R313.2
unnamed: D304.2 (A2), J302.2, R318.2
unnamed: D305.2 (A2), J301.3, R323.2
unnamed: D306.2 (A2), J302.3, R328.2
unnamed: D307.2 (A2), J301.4, R304.2
unnamed: D308.2 (A2), J302.4, R309.2
unnamed: D309.2 (A2), J301.5, R314.2
unnamed: D310.2 (A2), J302.5, R319.2
unnamed: D311.2 (A2), J301.6, R324.2
unnamed: D313.2 (A2), J301.7, R305.2
unnamed: D314.2 (A2), J302.7, R310.2
unnamed: D315.2 (A2), J301.8, R315.2
unnamed: D316.2 (A2), J302.8, R320.2
unnamed: D317.2 (A2), J301.9, R325.2
unnamed: D318.2 (A2), J302.9, R330.2
unnamed: D319.2 (A2), J301.10, R306.2
unnamed: D320.2 (A2), J302.10, R311.2
unnamed: D321.2 (A2), J301.11, R316.2
unnamed: D322.2 (A2), J302.11, R321.2
unnamed: D323.2 (A2), J301.12, R326.2
unnamed: D324.2 (A2), J302.12, R331.2
unnamed: D325.2 (A2), J301.13, R307.2
unnamed: D326.2 (A2), J302.13, R312.2
unnamed: D327.2 (A2), J301.14, R317.2
unnamed: D328.2 (A2), J302.14, R322.2
unnamed: D329.2 (A2), J301.15, R327.2
unnamed: D330.2 (A2), J302.15, R332.2
unnamed: JP301.1 (A), JP303.1 (A), JP305.1 (A), R301.2
unnamed: JP301.2 (C), U301.21 (A0)
unnamed: JP302.1 (A), JP304.1 (A), JP306.1 (A), R302.2
unnamed: JP302.2 (C), U302.21 (A0)
unnamed: JP303.2 (C), U301.2 (A1)
unnamed: JP304.2 (C), U302.2 (A1)
unnamed: JP305.2 (C), U301.3 (A2)
unnamed: JP306.2 (C), U302.3 (A2)

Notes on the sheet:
<- Right pin-header
<- Left pin-header
<- analog readback to Nucleo Tester ADC for POT verification

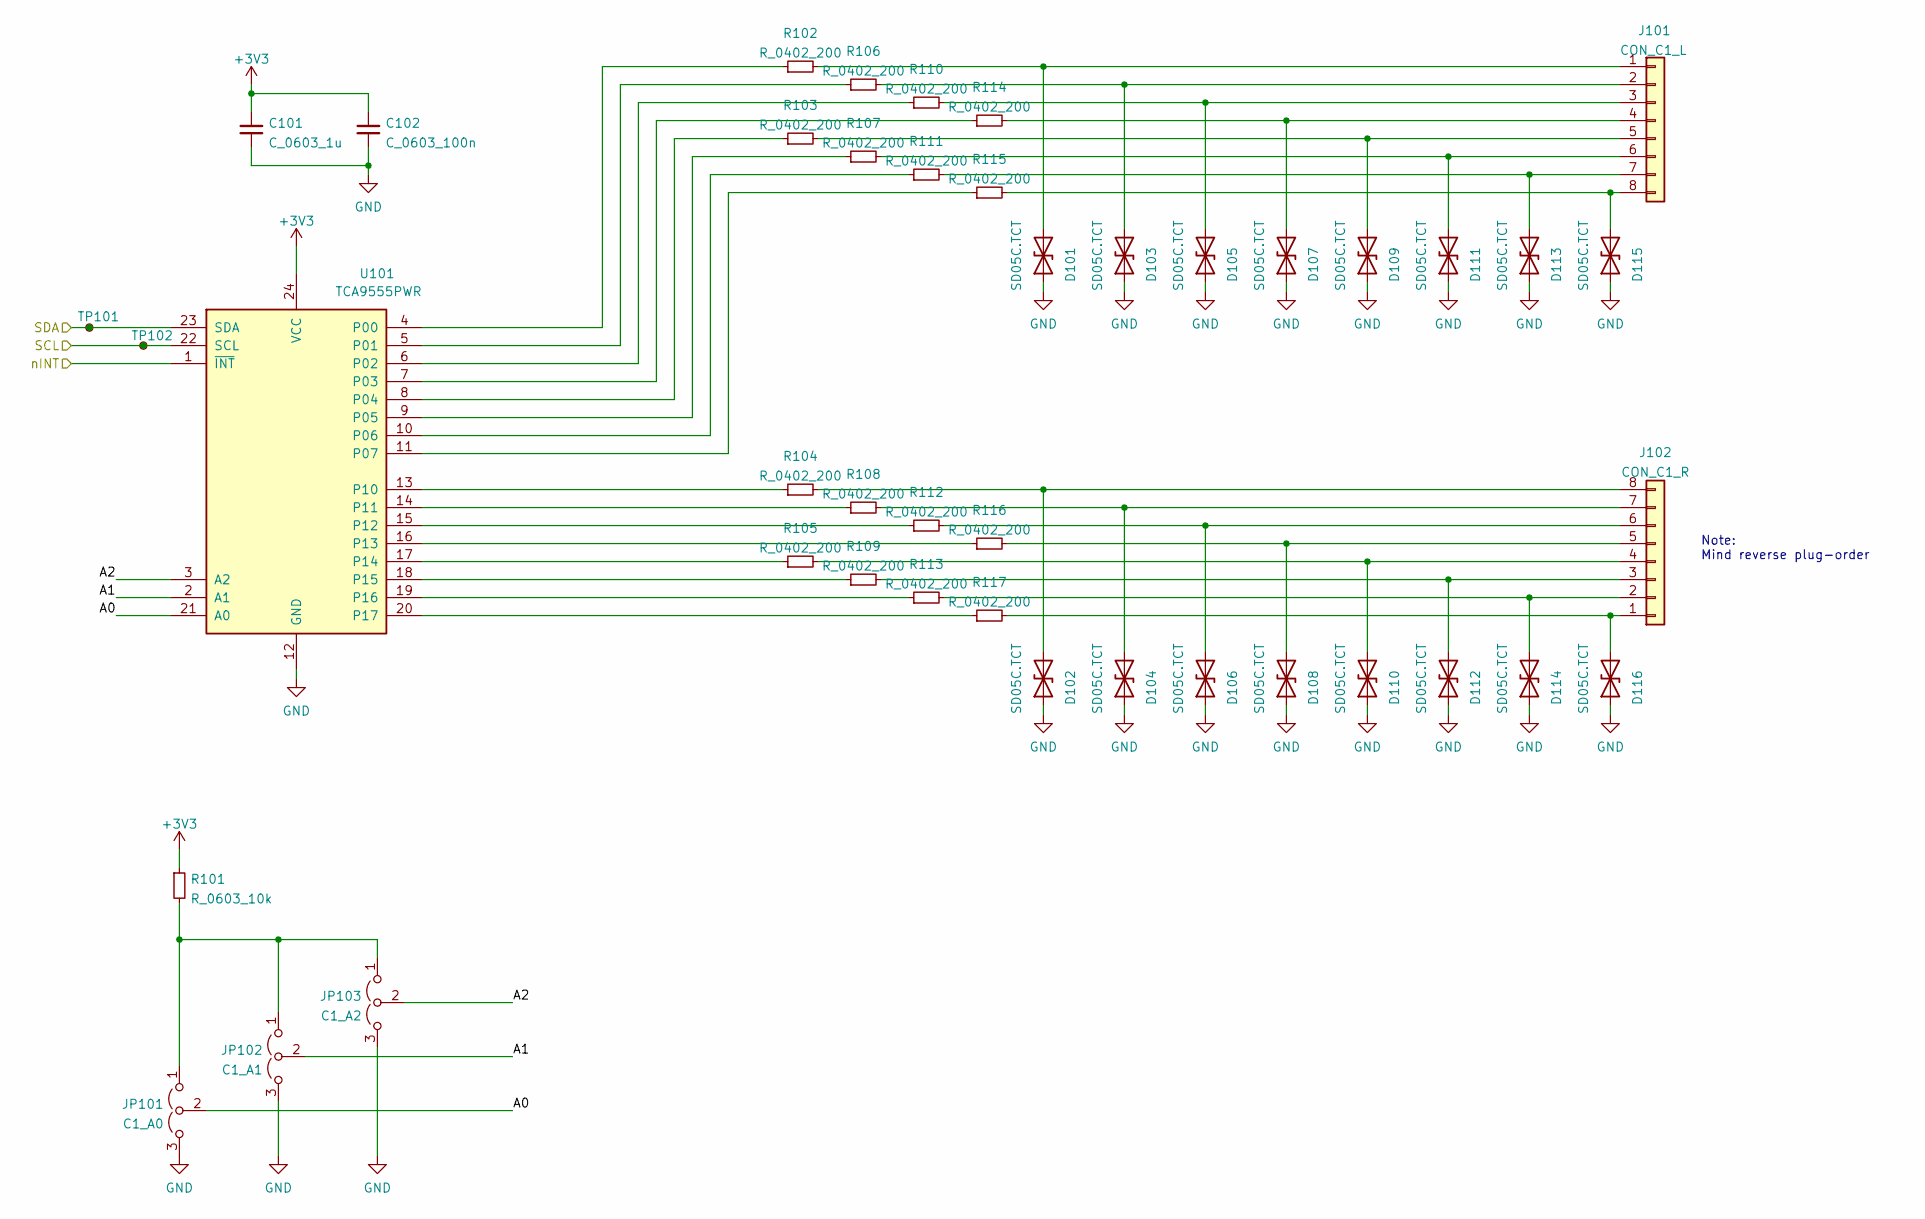
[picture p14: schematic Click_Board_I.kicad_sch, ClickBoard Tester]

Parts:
C101: C_0603_1u; C_0603_1608Metric; LCSC Part # C15849
C102: C_0603_100n; C_0603_1608Metric; LCSC Part # C14663
D101, D102, D103, D104, D105, D106, D107, D108, D109, D110, D111, D112, D113, D114, D115, D116: SD05C.TCT; D_SOD-323_HandSoldering; LCSC Part # C85200
J101: CON_C1_L; PinHeader_1x08_P2.54mm_Vertical
J102: CON_C1_R; PinHeader_1x08_P2.54mm_Vertical
JP101: C1_A0; SolderJumper-3_P1.3mm_Open_RoundedPad1.0x1.5mm
JP102: C1_A1; SolderJumper-3_P1.3mm_Open_RoundedPad1.0x1.5mm
JP103: C1_A2; SolderJumper-3_P1.3mm_Open_RoundedPad1.0x1.5mm
R101: R_0603_10k; R_0603_1608Metric; LCSC Part # C25804
R102, R103, R104, R105, R106, R107, R108, R109, R110, R111, R112, R113, R114, R115, R116, R117: R_0402_200; R_0402_1005Metric; LCSC Part # C25087
TP101, TP102: TestPoint_Small; TestPoint_Pad_D1.0mm
U101: TCA9555PWR; TSSOP-24_4.4x7.8mm_P0.65mm

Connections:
+3V3: C101.1, C102.1, R101.1, U101.24 (VCC); also elsewhere on the board
/Click_Board_I/A0: JP101.2 (C), U101.21 (A0)
/Click_Board_I/A1: JP102.2 (C), U101.2 (A1)
/Click_Board_I/A2: JP103.2 (C), U101.3 (A2)
/Click_Board_I/SCL: TP102.1, U101.22 (SCL); also elsewhere on the board
/Click_Board_I/SDA: TP101.1, U101.23 (SDA); also elsewhere on the board
/Click_Board_I/nINT: U101.1 (~INT); also elsewhere on the board
GND: C101.2, C102.2, D101.1 (A1), D102.1 (A1), D103.1 (A1), D104.1 (A1), D105.1 (A1), D106.1 (A1), D107.1 (A1), D108.1 (A1), D109.1 (A1), D110.1 (A1), D111.1 (A1), D112.1 (A1), D113.1 (A1), D114.1 (A1), D115.1 (A1), D116.1 (A1), JP101.3 (B), JP102.3 (B), JP103.3 (B), U101.12 (GND); also elsewhere on the board
unnamed: D101.2 (A2), J101.1, R102.2
unnamed: D102.2 (A2), J102.8, R104.2
unnamed: D103.2 (A2), J101.2, R106.2
unnamed: D104.2 (A2), J102.7, R108.2
unnamed: D105.2 (A2), J101.3, R110.2
unnamed: D106.2 (A2), J102.6, R112.2
unnamed: D107.2 (A2), J101.4, R114.2
unnamed: D108.2 (A2), J102.5, R116.2
unnamed: D109.2 (A2), J101.5, R103.2
unnamed: D110.2 (A2), J102.4, R105.2
unnamed: D111.2 (A2), J101.6, R107.2
unnamed: D112.2 (A2), J102.3, R109.2
unnamed: D113.2 (A2), J101.7, R111.2
unnamed: D114.2 (A2), J102.2, R113.2
unnamed: D115.2 (A2), J101.8, R115.2
unnamed: D116.2 (A2), J102.1, R117.2
unnamed: JP101.1 (A), JP102.1 (A), JP103.1 (A), R101.2
unnamed: R102.1, U101.4 (P00)
unnamed: R103.1, U101.8 (P04)
unnamed: R104.1, U101.13 (P10)
unnamed: R105.1, U101.17 (P14)
unnamed: R106.1, U101.5 (P01)
unnamed: R107.1, U101.9 (P05)
unnamed: R108.1, U101.14 (P11)
unnamed: R109.1, U101.18 (P15)
unnamed: R110.1, U101.6 (P02)
unnamed: R111.1, U101.10 (P06)
unnamed: R112.1, U101.15 (P12)
unnamed: R113.1, U101.19 (P16)
unnamed: R114.1, U101.7 (P03)
unnamed: R115.1, U101.11 (P07)
unnamed: R116.1, U101.16 (P13)
unnamed: R117.1, U101.20 (P17)

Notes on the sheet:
Note: Mind reverse plug-order

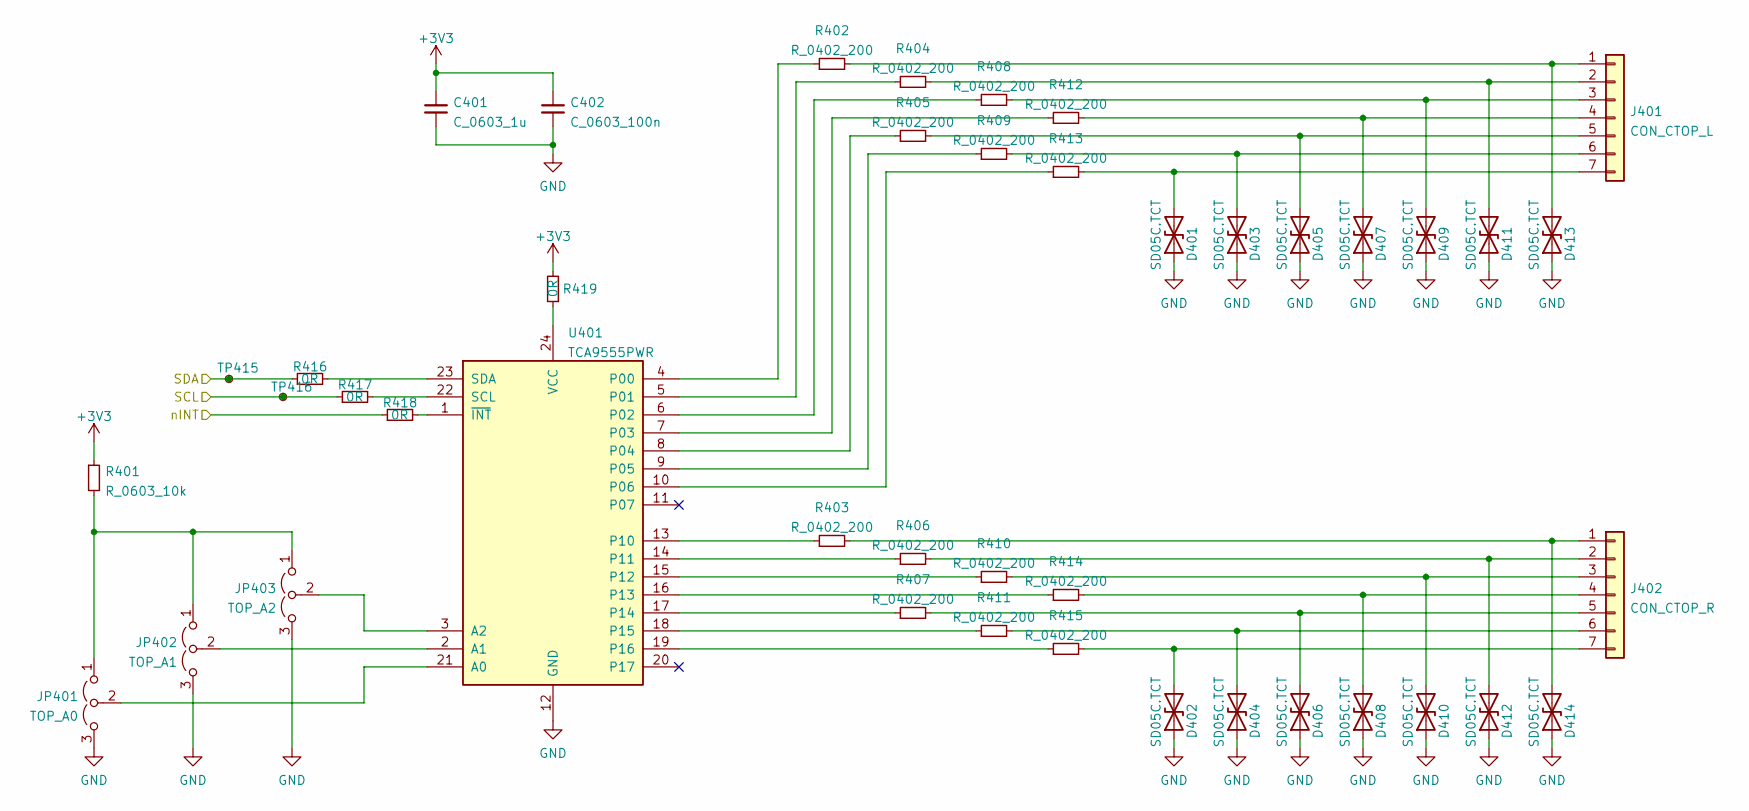
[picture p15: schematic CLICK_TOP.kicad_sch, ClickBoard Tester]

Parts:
C401: C_0603_1u; C_0603_1608Metric; LCSC Part # C15849
C402: C_0603_100n; C_0603_1608Metric; LCSC Part # C14663
D401, D402, D403, D404, D405, D406, D407, D408, D409, D410, D411, D412, D413, D414: SD05C.TCT; D_SOD-323_HandSoldering; LCSC Part # C85200
J401: CON_CTOP_L; PinHeader_1x07_P2.54mm_Vertical
J402: CON_CTOP_R; PinHeader_1x07_P2.54mm_Vertical
JP401: TOP_A0; SolderJumper-3_P1.3mm_Open_RoundedPad1.0x1.5mm
JP402: TOP_A1; SolderJumper-3_P1.3mm_Open_RoundedPad1.0x1.5mm
JP403: TOP_A2; SolderJumper-3_P1.3mm_Open_RoundedPad1.0x1.5mm
R401: R_0603_10k; R_0603_1608Metric; LCSC Part # C25804
R402, R403, R404, R405, R406, R407, R408, R409, R410, R411, R412, R413, R414, R415: R_0402_200; R_0402_1005Metric; LCSC Part # C25087
R416, R417, R418, R419: 0R; R_0603_1608Metric_Pad0.98x0.95mm_HandSolder; LCSC Part # C21189
TP415, TP416: TestPoint_Small; TestPoint_Pad_D1.0mm
U401: TCA9555PWR; TSSOP-24_4.4x7.8mm_P0.65mm

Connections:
+3V3: C401.1, C402.1, R401.1, R419.2; also elsewhere on the board
/MCU/MCU_PA9: R417.1, TP416.1; also elsewhere on the board
/MCU/MCU_PA10: R416.1, TP415.1; also elsewhere on the board
/MCU/MCU_PB6: R418.1; also elsewhere on the board
GND: C401.2, C402.2, D401.1 (A1), D402.1 (A1), D403.1 (A1), D404.1 (A1), D405.1 (A1), D406.1 (A1), D407.1 (A1), D408.1 (A1), D409.1 (A1), D410.1 (A1), D411.1 (A1), D412.1 (A1), D413.1 (A1), D414.1 (A1), JP401.3 (B), JP402.3 (B), JP403.3 (B), U401.12 (GND); also elsewhere on the board
unnamed: D401.2 (A2), J401.7, R413.2
unnamed: D402.2 (A2), J402.7, R415.2
unnamed: D403.2 (A2), J401.6, R409.2
unnamed: D404.2 (A2), J402.6, R411.2
unnamed: D405.2 (A2), J401.5, R405.2
unnamed: D406.2 (A2), J402.5, R407.2
unnamed: D407.2 (A2), J401.4, R412.2
unnamed: D408.2 (A2), J402.4, R414.2
unnamed: D409.2 (A2), J401.3, R408.2
unnamed: D410.2 (A2), J402.3, R410.2
unnamed: D411.2 (A2), J401.2, R404.2
unnamed: D412.2 (A2), J402.2, R406.2
unnamed: D413.2 (A2), J401.1, R402.2
unnamed: D414.2 (A2), J402.1, R403.2
unnamed: JP401.1 (A), JP402.1 (A), JP403.1 (A), R401.2
unnamed: JP401.2 (C), U401.21 (A0)
unnamed: JP402.2 (C), U401.2 (A1)
unnamed: JP403.2 (C), U401.3 (A2)
unnamed: R402.1, U401.4 (P00)
unnamed: R403.1, U401.13 (P10)
unnamed: R404.1, U401.5 (P01)
unnamed: R405.1, U401.8 (P04)
unnamed: R406.1, U401.14 (P11)
unnamed: R407.1, U401.17 (P14)
unnamed: R408.1, U401.6 (P02)
unnamed: R409.1, U401.9 (P05)
unnamed: R410.1, U401.15 (P12)
unnamed: R411.1, U401.18 (P15)
unnamed: R412.1, U401.7 (P03)
unnamed: R413.1, U401.10 (P06)
unnamed: R414.1, U401.16 (P13)
unnamed: R415.1, U401.19 (P16)
unnamed: R416.2, U401.23 (SDA)
unnamed: R417.2, U401.22 (SCL)
unnamed: R418.2, U401.1 (~INT)
unnamed: R419.1, U401.24 (VCC)

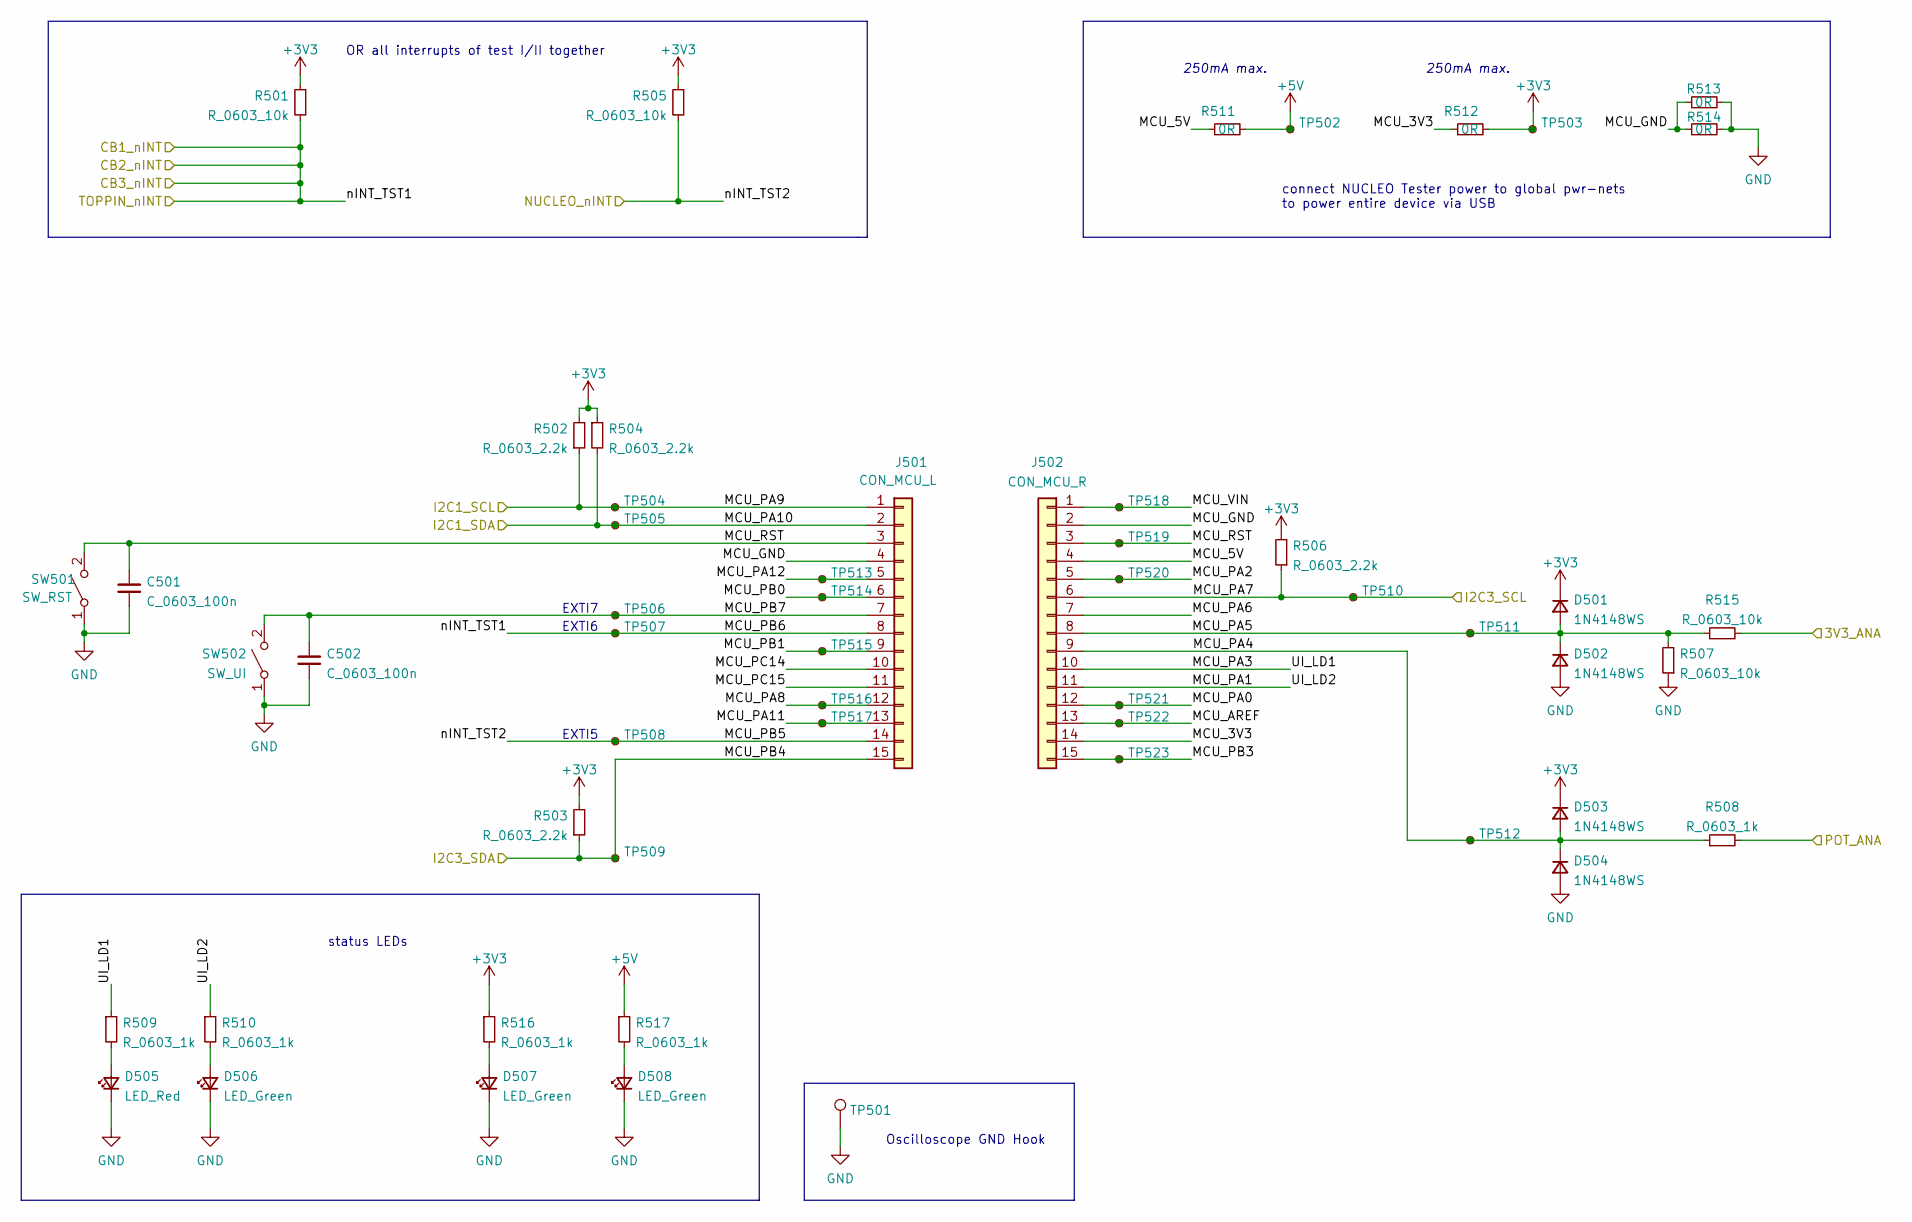
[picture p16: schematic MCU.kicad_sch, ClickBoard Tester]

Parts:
C501, C502: C_0603_100n; C_0603_1608Metric; LCSC Part # C14663
D501, D502, D503, D504: 1N4148WS; D_SOD-323F; LCSC Part # C2128
D505: LED_Red; LED_0603_1608Metric; LCSC Part # C2286
D506, D507, D508: LED_Green; LED_0603_1608Metric; LCSC Part # C72043
J501: CON_MCU_L; PinSocket_1x15_P2.54mm_Vertical
J502: CON_MCU_R; PinSocket_1x15_P2.54mm_Vertical
R501, R505, R507, R515: R_0603_10k; R_0603_1608Metric; LCSC Part # C25804
R502, R503, R504, R506: R_0603_2.2k; R_0603_1608Metric; LCSC Part # C4190
R508, R509, R510, R516, R517: R_0603_1k; R_0603_1608Metric; LCSC Part # C21190
R511, R512, R513, R514: 0R; R_0603_1608Metric_Pad0.98x0.95mm_HandSolder; LCSC Part # C21189
SW501: SW_RST; SW_PUSH_6mm
SW502: SW_UI; SW_PUSH_6mm
TP501: TestPoint; TestPoint_Keystone_5000-5004_Miniature
TP502, TP503, TP504, TP505, TP506, TP507, TP508, TP509, TP510, TP511, TP512, TP513, TP514, TP515, TP516, TP517, TP518, TP519, TP520, TP521, TP522, TP523: TestPoint_Small; TestPoint_Pad_D1.0mm

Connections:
+3V3: D501.1 (K), D503.1 (K), R501.1, R502.2, R503.2, R504.1, R505.1, R506.2, R512.2, R516.1, TP503.1; also elsewhere on the board
+5V: R511.2, R517.1, TP502.1; also elsewhere on the board
/MCU/MCU_3V3: J502.14, R512.1
/MCU/MCU_5V: J502.4, R511.1
/MCU/MCU_AREF: J502.13, TP522.1
/MCU/MCU_GND: J501.4, J502.2, R513.1, R514.1
/MCU/MCU_PA0: J502.12, TP521.1
/MCU/MCU_PA1: J502.11, R510.1
/MCU/MCU_PA2: J502.5, TP520.1
/MCU/MCU_PA3: J502.10, R509.1
/MCU/MCU_PA4: D503.2 (A), D504.1 (K), J502.9, R508.1, TP512.1
/MCU/MCU_PA5: D501.2 (A), D502.1 (K), J502.8, R507.2, R515.1, TP511.1
/MCU/MCU_PA6: J502.7
/MCU/MCU_PA7: J502.6, R506.1, TP510.1; also elsewhere on the board
/MCU/MCU_PA8: J501.12, TP516.1
/MCU/MCU_PA9: J501.1, R502.1, TP504.1; also elsewhere on the board
/MCU/MCU_PA10: J501.2, R504.2, TP505.1; also elsewhere on the board
/MCU/MCU_PA11: J501.13, TP517.1
/MCU/MCU_PA12: J501.5, TP513.1
/MCU/MCU_PB0: J501.6, TP514.1
/MCU/MCU_PB1: J501.9, TP515.1
/MCU/MCU_PB3: J502.15, TP523.1
/MCU/MCU_PB4: J501.15, R503.1, TP509.1; also elsewhere on the board
/MCU/MCU_PB5: J501.14, R505.2, TP508.1; also elsewhere on the board
/MCU/MCU_PB6: J501.8, R501.2, TP507.1; also elsewhere on the board
/MCU/MCU_PB7: C502.2, J501.7, SW502.2 (B), TP506.1
/MCU/MCU_PC14: J501.10
/MCU/MCU_PC15: J501.11
/MCU/MCU_RST: C501.2, J501.3, J502.3, SW501.2 (B), TP519.1
/MCU/MCU_VIN: J502.1, TP518.1
/MCU/POT_ANA: R508.2; also elsewhere on the board
/NUCLEO DUT/3V3_NUC: R515.2; also elsewhere on the board
GND: C501.1, C502.1, D502.2 (A), D504.2 (A), D505.1 (K), D506.1 (K), D507.1 (K), D508.1 (K), R507.1, R513.2, R514.2, SW501.1 (A), SW502.1 (A), TP501.1; also elsewhere on the board
unnamed: D505.2 (A), R509.2
unnamed: D506.2 (A), R510.2
unnamed: D507.2 (A), R516.2
unnamed: D508.2 (A), R517.2

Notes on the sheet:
250mA max.
EXTI5
connect NUCLEO Tester power to global pwr-nets to power entire device via USB
status LEDs
OR all interrupts of test I/II together
EXTI6
Oscilloscope GND Hook
EXTI7

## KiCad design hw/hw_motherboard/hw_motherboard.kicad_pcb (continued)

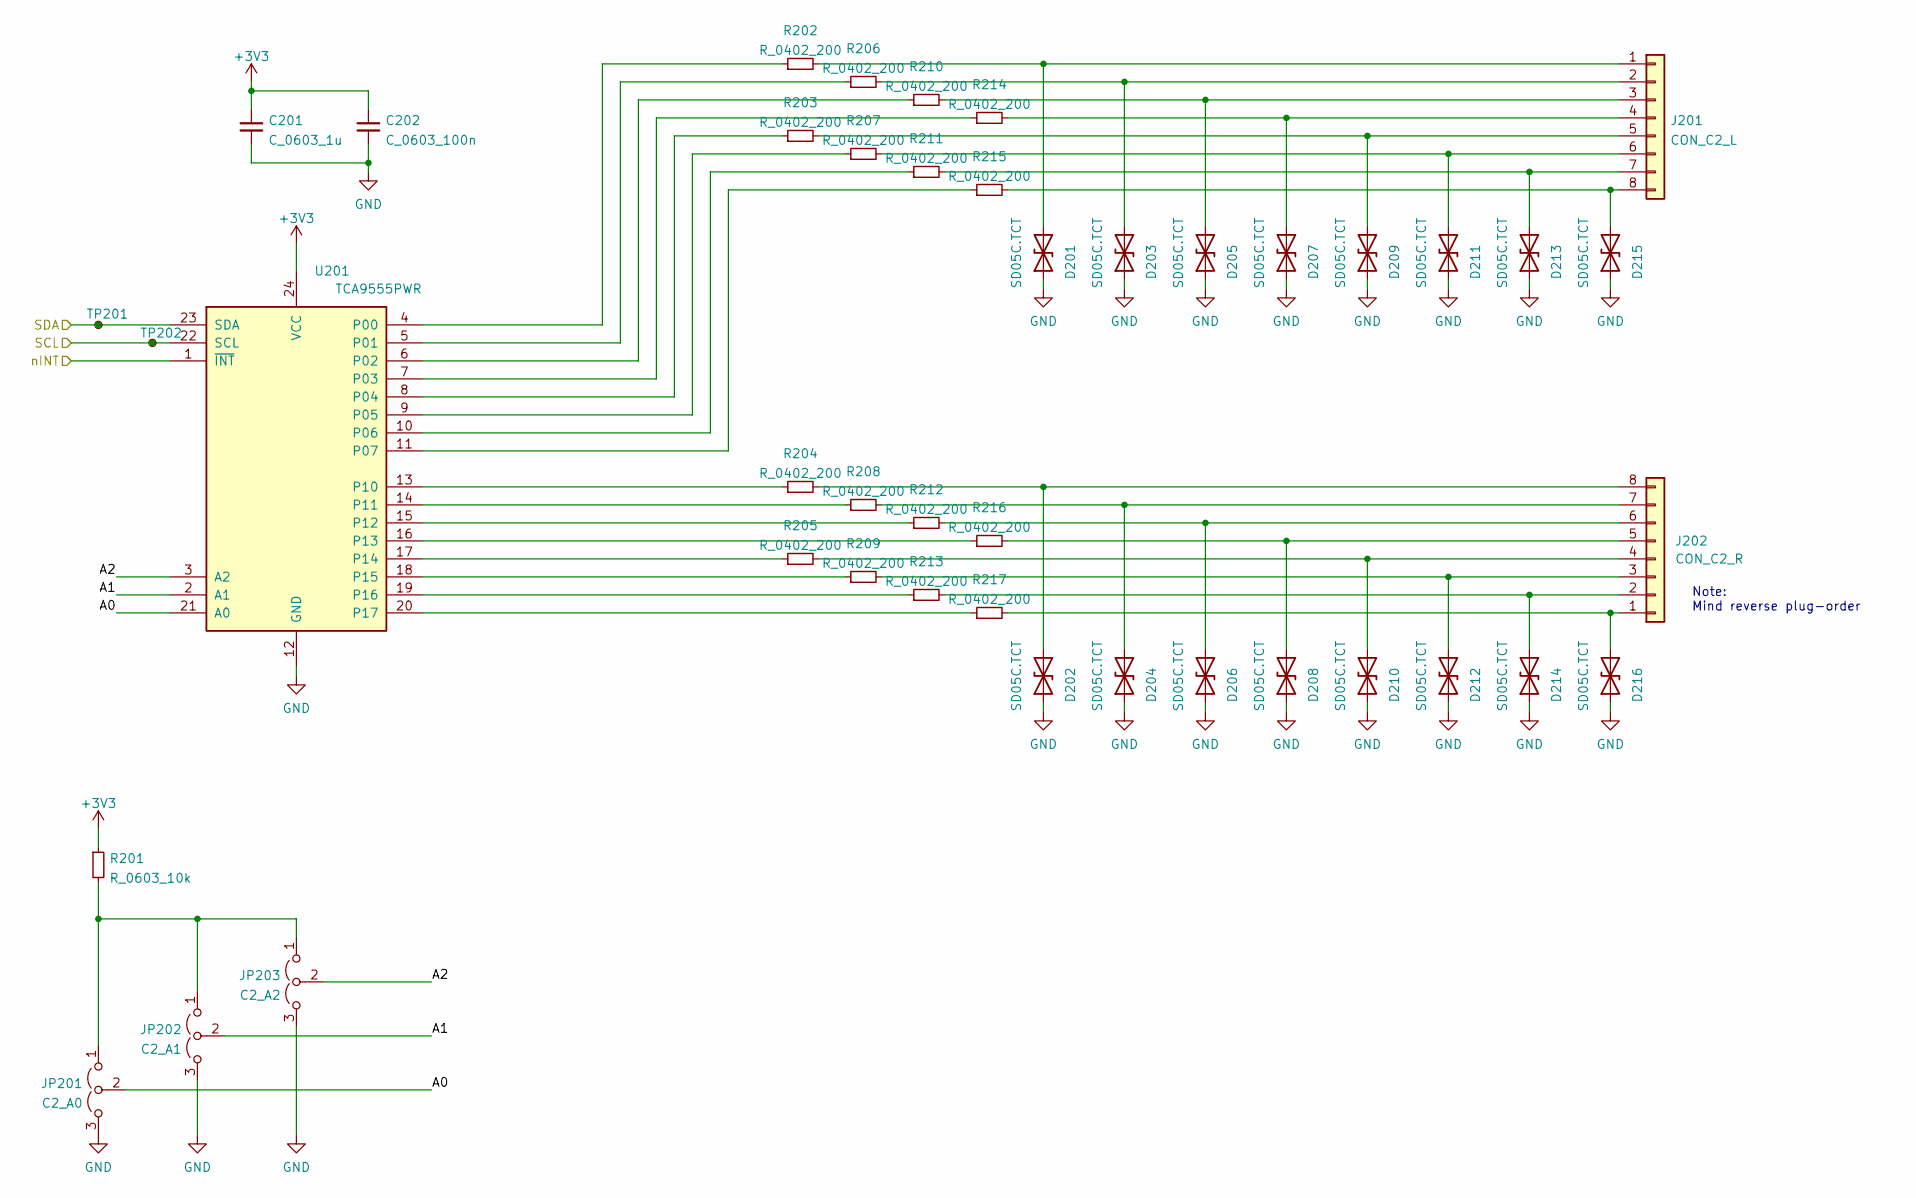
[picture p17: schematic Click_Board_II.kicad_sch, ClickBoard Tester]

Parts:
C201: C_0603_1u; C_0603_1608Metric; LCSC Part # C15849
C202: C_0603_100n; C_0603_1608Metric; LCSC Part # C14663
D201, D202, D203, D204, D205, D206, D207, D208, D209, D210, D211, D212, D213, D214, D215, D216: SD05C.TCT; D_SOD-323_HandSoldering; LCSC Part # C85200
J201: CON_C2_L; PinHeader_1x08_P2.54mm_Vertical
J202: CON_C2_R; PinHeader_1x08_P2.54mm_Vertical
JP201: C2_A0; SolderJumper-3_P1.3mm_Open_RoundedPad1.0x1.5mm
JP202: C2_A1; SolderJumper-3_P1.3mm_Open_RoundedPad1.0x1.5mm
JP203: C2_A2; SolderJumper-3_P1.3mm_Open_RoundedPad1.0x1.5mm
R201: R_0603_10k; R_0603_1608Metric; LCSC Part # C25804
R202, R203, R204, R205, R206, R207, R208, R209, R210, R211, R212, R213, R214, R215, R216, R217: R_0402_200; R_0402_1005Metric; LCSC Part # C25087
TP201, TP202: TestPoint_Small; TestPoint_Pad_D1.0mm
U201: TCA9555PWR; TSSOP-24_4.4x7.8mm_P0.65mm

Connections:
+3V3: C201.1, C202.1, R201.1, U201.24 (VCC); also elsewhere on the board
/Click_Board_II/A0: JP201.2 (C), U201.21 (A0)
/Click_Board_II/A1: JP202.2 (C), U201.2 (A1)
/Click_Board_II/A2: JP203.2 (C), U201.3 (A2)
/Click_Board_II/SCL: TP202.1, U201.22 (SCL); also elsewhere on the board
/Click_Board_II/SDA: TP201.1, U201.23 (SDA); also elsewhere on the board
/Click_Board_II/nINT: U201.1 (~INT); also elsewhere on the board
GND: C201.2, C202.2, D201.1 (A1), D202.1 (A1), D203.1 (A1), D204.1 (A1), D205.1 (A1), D206.1 (A1), D207.1 (A1), D208.1 (A1), D209.1 (A1), D210.1 (A1), D211.1 (A1), D212.1 (A1), D213.1 (A1), D214.1 (A1), D215.1 (A1), D216.1 (A1), JP201.3 (B), JP202.3 (B), JP203.3 (B), U201.12 (GND); also elsewhere on the board
unnamed: D201.2 (A2), J201.1, R202.2
unnamed: D202.2 (A2), J202.8, R204.2
unnamed: D203.2 (A2), J201.2, R206.2
unnamed: D204.2 (A2), J202.7, R208.2
unnamed: D205.2 (A2), J201.3, R210.2
unnamed: D206.2 (A2), J202.6, R212.2
unnamed: D207.2 (A2), J201.4, R214.2
unnamed: D208.2 (A2), J202.5, R216.2
unnamed: D209.2 (A2), J201.5, R203.2
unnamed: D210.2 (A2), J202.4, R205.2
unnamed: D211.2 (A2), J201.6, R207.2
unnamed: D212.2 (A2), J202.3, R209.2
unnamed: D213.2 (A2), J201.7, R211.2
unnamed: D214.2 (A2), J202.2, R213.2
unnamed: D215.2 (A2), J201.8, R215.2
unnamed: D216.2 (A2), J202.1, R217.2
unnamed: JP201.1 (A), JP202.1 (A), JP203.1 (A), R201.2
unnamed: R202.1, U201.4 (P00)
unnamed: R203.1, U201.8 (P04)
unnamed: R204.1, U201.13 (P10)
unnamed: R205.1, U201.17 (P14)
unnamed: R206.1, U201.5 (P01)
unnamed: R207.1, U201.9 (P05)
unnamed: R208.1, U201.14 (P11)
unnamed: R209.1, U201.18 (P15)
unnamed: R210.1, U201.6 (P02)
unnamed: R211.1, U201.10 (P06)
unnamed: R212.1, U201.15 (P12)
unnamed: R213.1, U201.19 (P16)
unnamed: R214.1, U201.7 (P03)
unnamed: R215.1, U201.11 (P07)
unnamed: R216.1, U201.16 (P13)
unnamed: R217.1, U201.20 (P17)

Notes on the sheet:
Note: Mind reverse plug-order

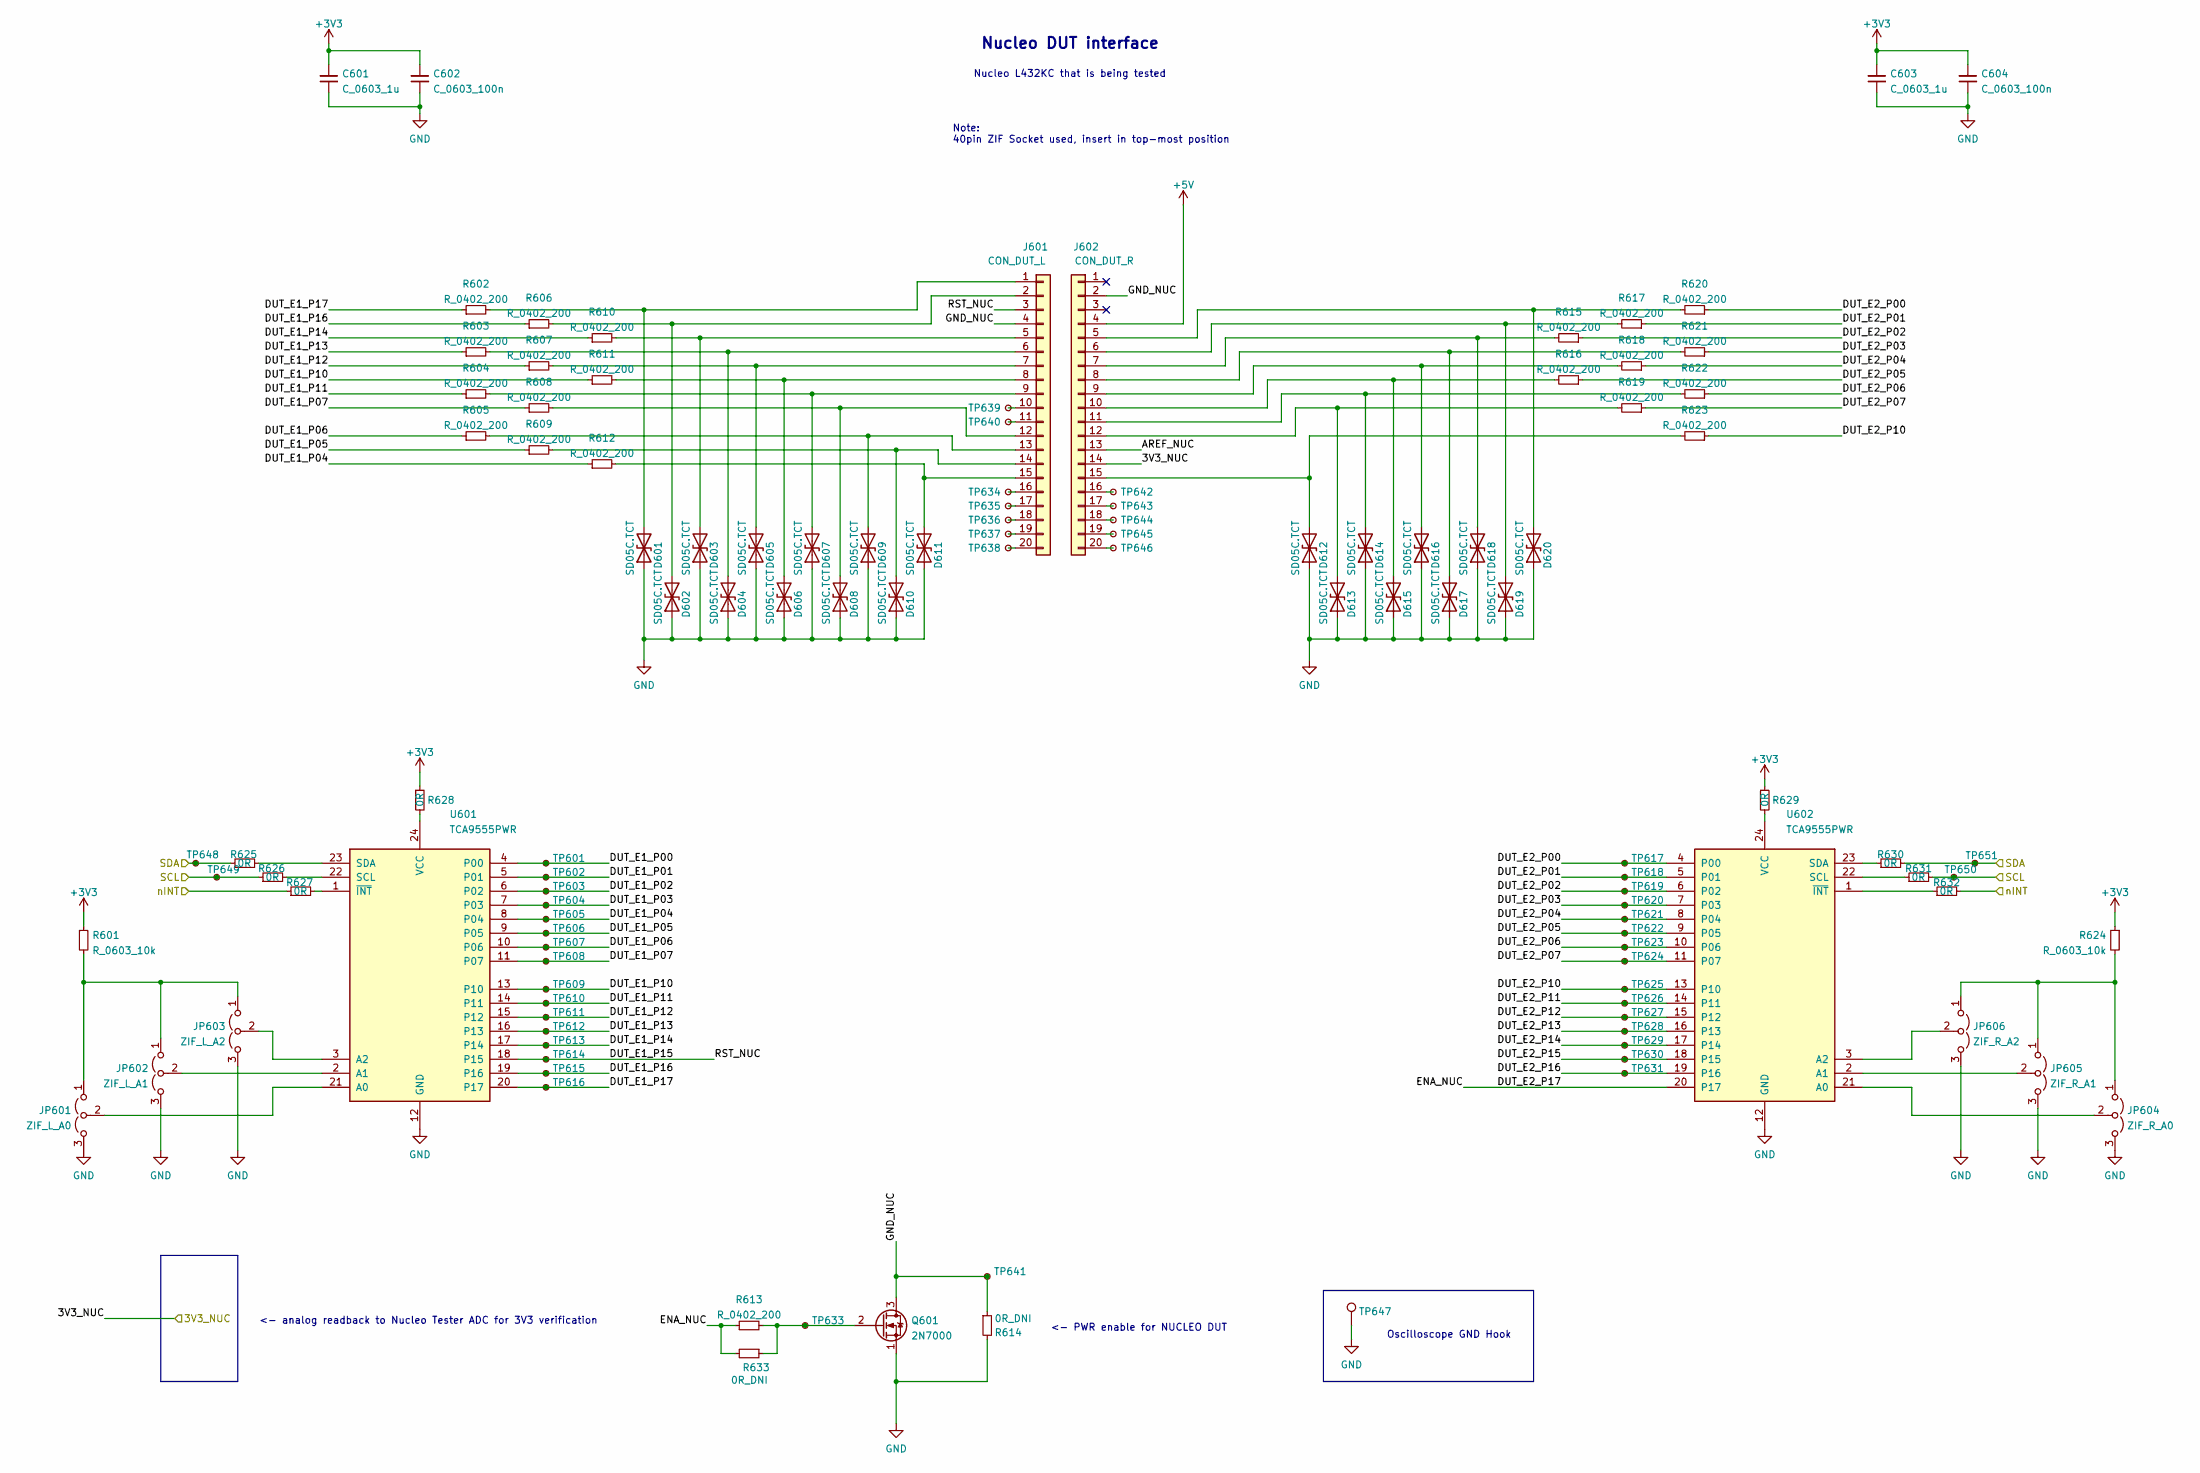
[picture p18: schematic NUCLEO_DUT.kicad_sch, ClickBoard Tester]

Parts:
C601, C603: C_0603_1u; C_0603_1608Metric; LCSC Part # C15849
C602, C604: C_0603_100n; C_0603_1608Metric; LCSC Part # C14663
D601, D602, D603, D604, D605, D606, D607, D608, D609, D610, D611, D612, D613, D614, D615, D616, D617, D618, D619, D620: SD05C.TCT; D_SOD-323_HandSoldering; LCSC Part # C85200
J601: CON_DUT_L; PinSocket_1x20_P2.54mm_Vertical
J602: CON_DUT_R; PinSocket_1x20_P2.54mm_Vertical
JP601: ZIF_L_A0; SolderJumper-3_P1.3mm_Open_RoundedPad1.0x1.5mm
JP602: ZIF_L_A1; SolderJumper-3_P1.3mm_Open_RoundedPad1.0x1.5mm
JP603: ZIF_L_A2; SolderJumper-3_P1.3mm_Open_RoundedPad1.0x1.5mm
JP604: ZIF_R_A0; SolderJumper-3_P1.3mm_Open_RoundedPad1.0x1.5mm
JP605: ZIF_R_A1; SolderJumper-3_P1.3mm_Open_RoundedPad1.0x1.5mm
JP606: ZIF_R_A2; SolderJumper-3_P1.3mm_Open_RoundedPad1.0x1.5mm
Q601: 2N7000; TO-92_Inline
R601, R624: R_0603_10k; R_0603_1608Metric; LCSC Part # C25804
R602, R603, R604, R605, R606, R607, R608, R609, R610, R611, R612, R613, R615, R616, R617, R618, R619, R620, R621, R622, R623: R_0402_200; R_0402_1005Metric; LCSC Part # C25087
R614, R633: 0R_DNI; R_0603_1608Metric_Pad0.98x0.95mm_HandSolder; LCSC Part # C21189
R625, R626, R627, R628, R629, R630, R631, R632: 0R; R_0603_1608Metric_Pad0.98x0.95mm_HandSolder; LCSC Part # C21189
TP601, TP602, TP603, TP604, TP605, TP606, TP607, TP608, TP609, TP610, TP611, TP612, TP613, TP614, TP615, TP616, TP617, TP618, TP619, TP620, TP621, TP622, TP623, TP624, TP625, TP626, TP627, TP628, TP629, TP630, TP631, TP633, TP634, TP635, TP636, TP637, TP638, TP639, TP640, TP641, TP642, TP643, TP644, TP645, TP646, TP648, TP649, TP650, TP651: TestPoint_Small; TestPoint_Pad_D1.0mm
TP647: TestPoint; TestPoint_Keystone_5000-5004_Miniature
U601, U602: TCA9555PWR; TSSOP-24_4.4x7.8mm_P0.65mm

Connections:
+3V3: C601.1, C602.1, C603.1, C604.1, R601.1, R624.1, R628.1, R629.1; also elsewhere on the board
+5V: J602.4; also elsewhere on the board
/MCU/MCU_PA7: R626.1, R631.2, TP649.1, TP650.1; also elsewhere on the board
/MCU/MCU_PB4: R625.1, R630.2, TP648.1, TP651.1; also elsewhere on the board
/MCU/MCU_PB5: R627.1, R632.2; also elsewhere on the board
/NUCLEO DUT/3V3_NUC: J602.14; also elsewhere on the board
/NUCLEO DUT/AREF_NUC: J602.13
/NUCLEO DUT/DUT_E1_P00: TP601.1, U601.4 (P00)
/NUCLEO DUT/DUT_E1_P01: TP602.1, U601.5 (P01)
/NUCLEO DUT/DUT_E1_P02: TP603.1, U601.6 (P02)
/NUCLEO DUT/DUT_E1_P03: TP604.1, U601.7 (P03)
/NUCLEO DUT/DUT_E1_P04: R612.1, TP605.1, U601.8 (P04)
/NUCLEO DUT/DUT_E1_P05: R609.1, TP606.1, U601.9 (P05)
/NUCLEO DUT/DUT_E1_P06: R605.1, TP607.1, U601.10 (P06)
/NUCLEO DUT/DUT_E1_P07: R608.1, TP608.1, U601.11 (P07)
/NUCLEO DUT/DUT_E1_P10: R611.1, TP609.1, U601.13 (P10)
/NUCLEO DUT/DUT_E1_P11: R604.1, TP610.1, U601.14 (P11)
/NUCLEO DUT/DUT_E1_P12: R607.1, TP611.1, U601.15 (P12)
/NUCLEO DUT/DUT_E1_P13: R603.1, TP612.1, U601.16 (P13)
/NUCLEO DUT/DUT_E1_P14: R610.1, TP613.1, U601.17 (P14)
/NUCLEO DUT/DUT_E1_P15: J601.3, TP614.1, U601.18 (P15)
/NUCLEO DUT/DUT_E1_P16: R606.1, TP615.1, U601.19 (P16)
/NUCLEO DUT/DUT_E1_P17: R602.1, TP616.1, U601.20 (P17)
/NUCLEO DUT/DUT_E2_P00: R620.1, TP617.1, U602.4 (P00)
/NUCLEO DUT/DUT_E2_P01: R617.1, TP618.1, U602.5 (P01)
/NUCLEO DUT/DUT_E2_P02: R615.1, TP619.1, U602.6 (P02)
/NUCLEO DUT/DUT_E2_P03: R621.1, TP620.1, U602.7 (P03)
/NUCLEO DUT/DUT_E2_P04: R618.1, TP621.1, U602.8 (P04)
/NUCLEO DUT/DUT_E2_P05: R616.1, TP622.1, U602.9 (P05)
/NUCLEO DUT/DUT_E2_P06: R622.1, TP623.1, U602.10 (P06)
/NUCLEO DUT/DUT_E2_P07: R619.1, TP624.1, U602.11 (P07)
/NUCLEO DUT/DUT_E2_P10: R623.1, TP625.1, U602.13 (P10)
/NUCLEO DUT/DUT_E2_P11: TP626.1, U602.14 (P11)
/NUCLEO DUT/DUT_E2_P12: TP627.1, U602.15 (P12)
/NUCLEO DUT/DUT_E2_P13: TP628.1, U602.16 (P13)
/NUCLEO DUT/DUT_E2_P14: TP629.1, U602.17 (P14)
/NUCLEO DUT/DUT_E2_P15: TP630.1, U602.18 (P15)
/NUCLEO DUT/DUT_E2_P16: TP631.1, U602.19 (P16)
/NUCLEO DUT/DUT_E2_P17: R613.1, R633.2, U602.20 (P17)
/NUCLEO DUT/GND_NUC: J601.4, J602.2, Q601.3 (D), R614.1, TP641.1
GND: C601.2, C602.2, C603.2, C604.2, D601.1 (A1), D602.1 (A1), D603.1 (A1), D604.1 (A1), D605.1 (A1), D606.1 (A1), D607.1 (A1), D608.1 (A1), D609.1 (A1), D610.1 (A1), D611.1 (A1), D612.1 (A1), D613.1 (A1), D614.1 (A1), D615.1 (A1), D616.1 (A1), D617.1 (A1), D618.1 (A1), D619.1 (A1), D620.1 (A1), JP601.3 (B), JP602.3 (B), JP603.3 (B), JP604.3 (B), JP605.3 (B), JP606.3 (B), Q601.1 (S), R614.2, TP647.1, U601.12 (GND), U602.12 (GND); also elsewhere on the board
unnamed: D601.2 (A2), J601.1, R602.2
unnamed: D602.2 (A2), J601.2, R606.2
unnamed: D603.2 (A2), J601.5, R610.2
unnamed: D604.2 (A2), J601.6, R603.2
unnamed: D605.2 (A2), J601.7, R607.2
unnamed: D606.2 (A2), J601.8, R611.2
unnamed: D607.2 (A2), J601.9, R604.2
unnamed: D608.2 (A2), J601.12, R608.2
unnamed: D609.2 (A2), J601.13, R605.2
unnamed: D610.2 (A2), J601.14, R609.2
unnamed: D611.2 (A2), J601.15, R612.2
unnamed: D612.2 (A2), J602.15, R623.2
unnamed: D613.2 (A2), J602.12, R619.2
unnamed: D614.2 (A2), J602.11, R622.2
unnamed: D615.2 (A2), J602.10, R616.2
unnamed: D616.2 (A2), J602.9, R618.2
unnamed: D617.2 (A2), J602.8, R621.2
unnamed: D618.2 (A2), J602.7, R615.2
unnamed: D619.2 (A2), J602.6, R617.2
unnamed: D620.2 (A2), J602.5, R620.2
unnamed: J601.10, TP639.1
unnamed: J601.11, TP640.1
unnamed: J601.16, TP634.1
unnamed: J601.17, TP635.1
unnamed: J601.18, TP636.1
unnamed: J601.19, TP637.1
unnamed: J601.20, TP638.1
unnamed: J602.16, TP642.1
unnamed: J602.17, TP643.1
unnamed: J602.18, TP644.1
unnamed: J602.19, TP645.1
unnamed: J602.20, TP646.1
unnamed: JP601.1 (A), JP602.1 (A), JP603.1 (A), R601.2
unnamed: JP601.2 (C), U601.21 (A0)
unnamed: JP602.2 (C), U601.2 (A1)
unnamed: JP603.2 (C), U601.3 (A2)
unnamed: JP604.1 (A), JP605.1 (A), JP606.1 (A), R624.2
unnamed: JP604.2 (C), U602.21 (A0)
unnamed: JP605.2 (C), U602.2 (A1)
unnamed: JP606.2 (C), U602.3 (A2)
unnamed: Q601.2 (G), R613.2, R633.1, TP633.1
unnamed: R625.2, U601.23 (SDA)
unnamed: R626.2, U601.22 (SCL)
unnamed: R627.2, U601.1 (~INT)
unnamed: R628.2, U601.24 (VCC)
unnamed: R629.2, U602.24 (VCC)
unnamed: R630.1, U602.23 (SDA)
unnamed: R631.1, U602.22 (SCL)
unnamed: R632.1, U602.1 (~INT)

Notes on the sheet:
<- analog readback to Nucleo Tester ADC for 3V3 verification
Nucleo L432KC that is being tested
Oscilloscope GND Hook
<- PWR enable for NUCLEO DUT
Note: 40pin ZIF Socket used, insert in top-most position
Nucleo DUT interface

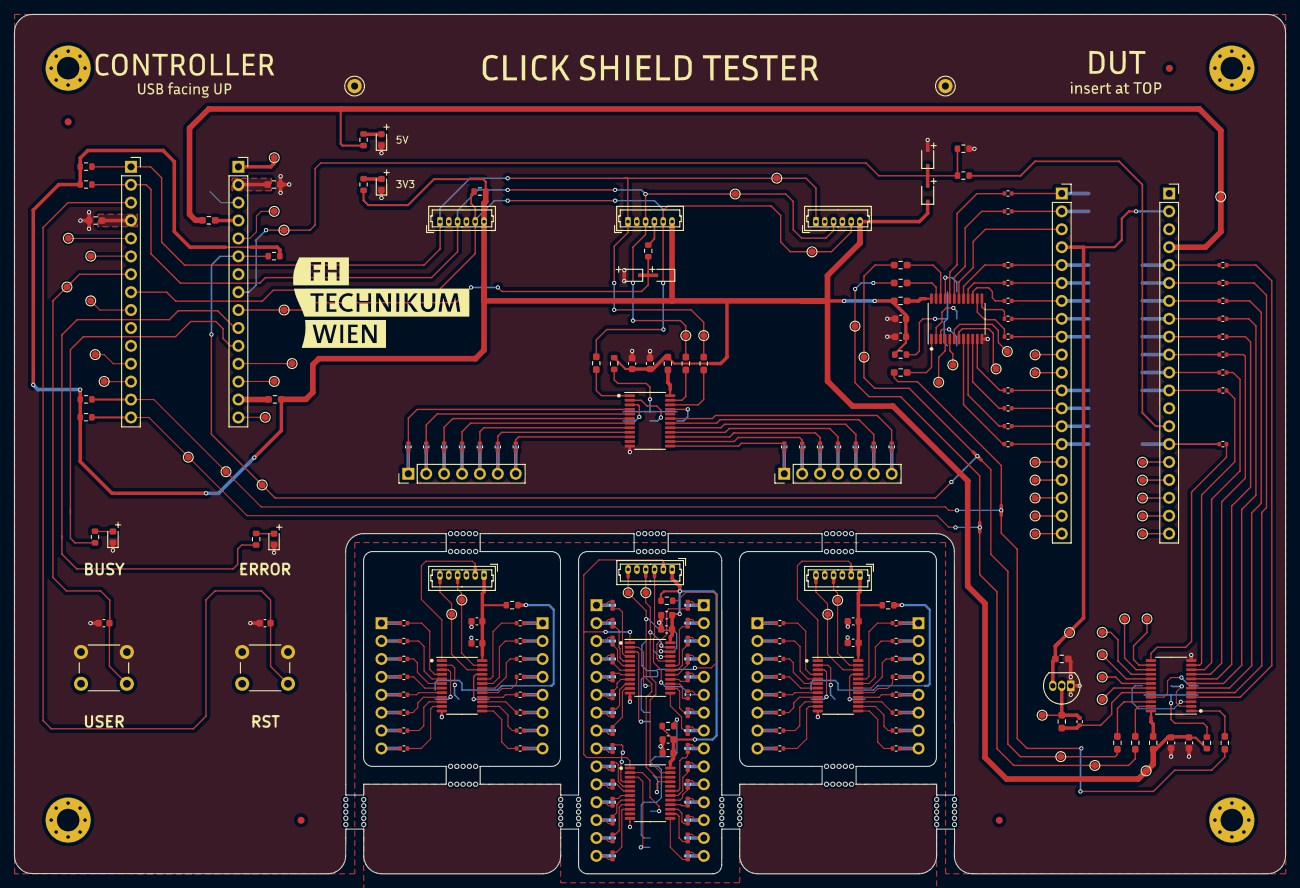
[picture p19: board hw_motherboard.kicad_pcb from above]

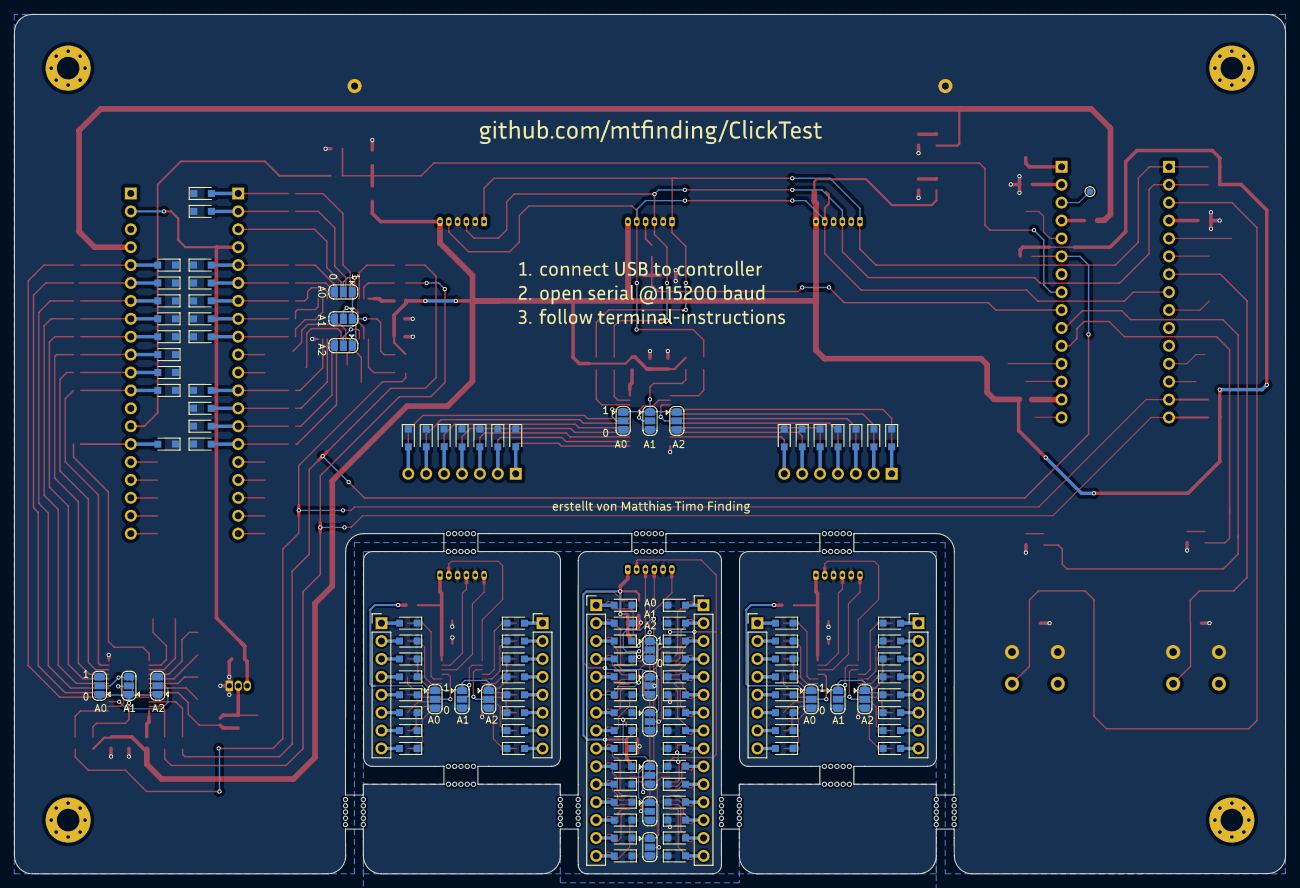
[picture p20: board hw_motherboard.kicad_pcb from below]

Board: 2 copper layers, 180.3 x 121.9 mm, 381 parts (124 on the bottom side), 301 nets.

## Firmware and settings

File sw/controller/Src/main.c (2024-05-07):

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
/* Includes ------------------------------------------------------------------*/
#include "main.h"

/* USER CODE BEGIN Includes */
#include <IO_control.h>
#include <IO_test.h>
#include <userInterface.h>
#include <stdio.h>
#include <stdbool.h>

/* USER CODE END Includes */

/* USER CODE BEGIN PD */

// UART rx buffer
char UART_RX_BUF[UART_RX_LEN];

// user interface input command
uint8_t UI_NEXT_CMD = 0;
uint8_t UI_ACT_FLAG = 0;

/* USER CODE END PD */

ADC_HandleTypeDef hadc1;

I2C_HandleTypeDef hi2c1;
I2C_HandleTypeDef hi2c3;

UART_HandleTypeDef huart2;
DMA_HandleTypeDef hdma_usart2_rx;

void SystemClock_Config(void);
static void MX_GPIO_Init(void);
static void MX_DMA_Init(void);
static void MX_USART2_UART_Init(void);
static void MX_ADC1_Init(void);
static void MX_I2C1_Init(void);
static void MX_I2C3_Init(void);
/* USER CODE BEGIN PFP */

/*--------- setup scanf/printf over UART2 (serial interface to PC) -----------*/
#ifdef __GNUC__
#define PUTCHAR_PROTOTYPE int __io_putchar(int ch)
#define GETCHAR_PROTOTYPE int __io_getchar(void)
#else
#define PUTCHAR_PROTOTYPE int fputc(int ch, FILE *f)
#define GETCHAR_PROTOTYPE int fgetc(FILE *f)
#endif

PUTCHAR_PROTOTYPE
{
  HAL_UART_Transmit(&huart2, (uint8_t *)&ch, 1, HAL_MAX_DELAY);
  return ch;
}

GETCHAR_PROTOTYPE
{
  uint8_t ch = 0;

  /* Clear the Overrun flag just before receiving the first character */
  __HAL_UART_CLEAR_OREFLAG(&huart2);

  /* Wait for reception of a character on the USART RX line and echo this
   * character on console */
  HAL_UART_Receive(&huart2, (uint8_t *)&ch, 1, HAL_MAX_DELAY);
  HAL_UART_Transmit(&huart2, (uint8_t *)&ch, 1, HAL_MAX_DELAY);
  return ch;
}
/*----------------------------------------------------------------------------*/

/* USER CODE END PFP */

/**
  * @brief  The application entry point.
  * @retval int
  */
int main(void)
{
  /* MCU Configuration--------------------------------------------------------*/

  /* Reset of all peripherals, Initializes the Flash interface and the Systick. */
  HAL_Init();

  /* USER CODE BEGIN Init */

  // disable stdio buffers to avoid UART miscommunications
  setvbuf(stdin, NULL, _IONBF, 0);

  /* USER CODE END Init */

  /* Configure the system clock */
  SystemClock_Config();

  /* Initialize all configured peripherals */
  MX_GPIO_Init();
  MX_DMA_Init();
  MX_USART2_UART_Init();
  MX_ADC1_Init();
  MX_I2C1_Init();
  MX_I2C3_Init();
  /* USER CODE BEGIN 2 */

	// UART receive to DMA setup

	// initial start of UART to DMA transaction
	HAL_UARTEx_ReceiveToIdle_DMA(&huart2, (uint8_t *)UART_RX_BUF, UART_RX_LEN);

	// disable half-transfer interrupt (DMA_IT_HT)
	__HAL_DMA_DISABLE_IT(&hdma_usart2_rx, DMA_IT_HT);

  /* USER CODE END 2 */

  /* Infinite loop */
  /* USER CODE BEGIN WHILE */

	// test sequence for GPIO extender evaluation
//	reset_io();
//	node_output_high(CB_L_GND_1);
//	node_output_low(CB_L_GND_1);
//	node_release(CB_L_GND_1);

	// test sequence for ADC evaluation
//	reset_io();
//	uint16_t adc_sample;
//	HAL_ADC_Start(&hadc1);
//	HAL_ADC_PollForConversion(&hadc1, 100);
//	adc_sample = HAL_ADC_GetValue(&hadc1);
//	HAL_ADC_Stop(&hadc1);
//	printf("ADC: %d\r\n", adc_sample);

	// test sequence for I2C evaluation
//	write_register(CB_L_3V3.addr, 0x04, 0xFF); // write FF to polarity inversion register
//	read_register(CB_L_3V3.addr, 0x04); // write FF to polarity inversion register
//	Error_Handler();

	// test sequence for GPIO evaluation
//	reset_io();
//	uint8_t base_address = 0b01100000;
//	node_t dummy_node = {"DUMMY", 0b00000000};
//	for(uint8_t i = 0; i<16; i++){
//		dummy_node.addr = base_address + i;
//		node_output_high(dummy_node);
//	}
//
//	for(uint8_t i = 0; i<16; i++){
//		dummy_node.addr = base_address + i;
//		node_output_low(dummy_node);
//	}
//	Error_Handler();


  // reset IO expanders
  reset_io();

  // deactivate Nucleo pwr
  node_output_low(MB_DUT_ENA);

  // print welcome message
  print_header();

	while (1)
	{

    /*-------------------------*
     *    main control loop    *
     *-------------------------*/

		if(UI_ACT_FLAG == 1){

      // reset flag
			UI_ACT_FLAG = 0;

      // execute command
			switch(UI_NEXT_CMD){

			case UI_EXEC_NUC:
        // reset error-led from previous test
        set_error_led(LED_OFF);
        // start requested test
				nuc_master_test();
        // re-start DMA-UART buffer after execution
				HAL_UARTEx_ReceiveToIdle_DMA(&huart2, (uint8_t *)UART_RX_BUF, UART_RX_LEN);
				break;

			case UI_EXEC_CB:
        // reset error-led from previous test
        set_error_led(LED_OFF);
        // start requested test
				cb_master_test();
        // re-start DMA-UART buffer after execution
				HAL_UARTEx_ReceiveToIdle_DMA(&huart2, (uint8_t *)UART_RX_BUF, UART_RX_LEN);
				break;

			case UI_EXEC_ALL:
        // reset error-led from previous test
        set_error_led(LED_OFF);
        // start requested test
				test_all();
        // re-start DMA-UART buffer after execution
				HAL_UARTEx_ReceiveToIdle_DMA(&huart2, (uint8_t *)UART_RX_BUF, UART_RX_LEN);
				break;

			default:
        // _NOP and restart DMA-UART buffer
				HAL_UARTEx_ReceiveToIdle_DMA(&huart2, (uint8_t *)UART_RX_BUF, UART_RX_LEN);
				break;
			}
		}

		/* USER CODE END WHILE */

		/* USER CODE BEGIN 3 */

	}
  /* USER CODE END 3 */
}

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
/* USER CODE BEGIN 4 */

// user inputs via button or uart trigger system action interrupts

// user-button ISR handler
void HAL_GPIO_EXTI_Callback(uint16_t GPIO_Pin){
    if(GPIO_Pin == GPIO_PIN_7){

      // check for active-flag to avoid double execution
    	if(UI_ACT_FLAG != 1){

        // set flag to indicate new user-command
        UI_ACT_FLAG = 1;

        // get next operation from button-mapped command
        UI_NEXT_CMD = button_handler();
      }

    }
}

// UART IDLE or buffer-full interrupt handler
void HAL_UARTEx_RxEventCallback(UART_HandleTypeDef *huart, uint16_t Size){
	if (huart->Instance == USART2){

    // set flag to indicate new user-command
		UI_ACT_FLAG = 1;

    // get next operation from user command
		UI_NEXT_CMD = parse_input(UART_RX_BUF);
	}
}

/* USER CODE END 4 */
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


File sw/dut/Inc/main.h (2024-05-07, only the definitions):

#define MCO_Pin GPIO_PIN_0
#define MCO_GPIO_Port GPIOA
#define A1_Pin GPIO_PIN_1
#define A1_GPIO_Port GPIOA
#define VCP_TX_Pin GPIO_PIN_2
#define VCP_TX_GPIO_Port GPIOA
#define A2_Pin GPIO_PIN_3
#define A2_GPIO_Port GPIOA
#define A3_Pin GPIO_PIN_4
#define A3_GPIO_Port GPIOA
#define A4_D4_Pin GPIO_PIN_5
#define A4_D4_GPIO_Port GPIOA
#define A5_D5_Pin GPIO_PIN_6
#define A5_D5_GPIO_Port GPIOA
#define A6_Pin GPIO_PIN_7
#define A6_GPIO_Port GPIOA
#define D3_Pin GPIO_PIN_0
#define D3_GPIO_Port GPIOB
#define D6_Pin GPIO_PIN_1
#define D6_GPIO_Port GPIOB
#define D9_Pin GPIO_PIN_8
#define D9_GPIO_Port GPIOA
#define D1_Pin GPIO_PIN_9
#define D1_GPIO_Port GPIOA
#define D0_Pin GPIO_PIN_10
#define D0_GPIO_Port GPIOA
#define D10_Pin GPIO_PIN_11
#define D10_GPIO_Port GPIOA
#define D2_Pin GPIO_PIN_12
#define D2_GPIO_Port GPIOA
#define SWDIO_Pin GPIO_PIN_13
#define SWDIO_GPIO_Port GPIOA
#define SWCLK_Pin GPIO_PIN_14
#define SWCLK_GPIO_Port GPIOA
#define VCP_RX_Pin GPIO_PIN_15
#define VCP_RX_GPIO_Port GPIOA
#define D13_Pin GPIO_PIN_3
#define D13_GPIO_Port GPIOB
#define D12_Pin GPIO_PIN_4
#define D12_GPIO_Port GPIOB
#define D11_Pin GPIO_PIN_5
#define D11_GPIO_Port GPIOB
#define D5_A5_INPUT_Pin GPIO_PIN_6
#define D5_A5_INPUT_GPIO_Port GPIOB
#define D4_A4_INPUT_Pin GPIO_PIN_7
#define D4_A4_INPUT_GPIO_Port GPIOB

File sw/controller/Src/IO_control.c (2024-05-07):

/* ========================================================================== *
 * FileName: IO_control.c
 * Description: Library for IO interactions with GPIO-Expander: TI tca9555
 * Author: Matthias Timo Finding
 * Creation Date: Oct 6, 2023
 * Modified Date: Feb 10, 2024
 * Version: 1
 * ========================================================================== */

#include <main.h>
#include <stdbool.h>
#include <stdio.h>
#include <IO_control.h>

/**
  * @brief: convert from node-bitpattern to one-hot-code
  * for I/O expander registers (refer IO_control.h: 69)
  * @note: selecting single pin on port expander requires one-hot-code
  * for upper and lower register respectively
  * @param: targeted node
  * @retval: one-hot-code for port-expander write operation
  */
uint8_t get_one_hot(uint8_t node_address) {

	// get expander pin number from last 3(2-0) bits -> n
    uint8_t expander_node_id = node_address & 0b00000111;
    return 0x01 << expander_node_id;
}

/**
  * @brief: get I2C device address from node-bitpattern
  * @note: for write_register() and read_register() functions
  * @param: targeted node
  * @retval: I2C device address
  */
uint8_t get_device_address(uint8_t node_address){

	// shift device addr so A0 = LSB and remove rest
	uint8_t device_address = (node_address >> 4) & 0b00000111;

	// bring to expected format for tca9555
	return (0b00100000 | device_address) << 1;
}

/**
  * @brief: write port expander register
  * auto-selects required I2C port depending on address
  * @param: addr: address(any node of targeted device)
  * @param: reg: register to write
  * @param: data: data to write
  * @retval: I2C write operation success
  */
_Bool write_register(uint8_t node_address, uint8_t reg, uint8_t data){

	uint8_t device_address = get_device_address(node_address);
	uint8_t packet[2] = {reg, data};

	// select correct I2C instance depending on MSB of pin-bit-pattern
	I2C_HandleTypeDef *I2C_PORT = (node_address & 0x80) ? &hi2c3 : &hi2c1;

	if(HAL_I2C_Master_Transmit(	I2C_PORT,
								device_address,
								packet,
								2,
								I2C_DEF_TIMEOUT) == HAL_OK){
		return true;
	} else {
		return false;
	}
}

/**
  * @brief: read port expander register
  * @param: address(any node of targeted device) and register
  * @retval: register value
  */
uint8_t read_register(uint8_t node_address, uint8_t reg){

	uint8_t device_address = get_device_address(node_address);
	uint8_t return_data;

	// select correct I2C instance depending on MSB of pin-bit-pattern
	I2C_HandleTypeDef *I2C_PORT = (node_address & 0x80) ? &hi2c3 : &hi2c1;

	HAL_I2C_Master_Transmit(I2C_PORT, device_address, &reg, 1, I2C_DEF_TIMEOUT);
	HAL_I2C_Master_Receive(I2C_PORT, device_address, &return_data, 1, I2C_DEF_TIMEOUT);

	return return_data;
}

/**
  * @brief: Write function for addressing individual nodes
  * @param: target node and states: IO_LOW or IO_HIGH
  * @retval: none
  * @note: targets output-register of port expander
  */
_Bool write_node(node_t node, uint8_t state){

	_Bool retVal;

	// read current register contents
	uint8_t old_reg_value[2] = {read_register(node.addr, REG_OUTPUT0),
		read_register(node.addr, REG_OUTPUT1)};

	// generate bitmask of tagrgeted pin
	uint8_t bitmask = get_one_hot(node.addr);

	// select upper or lower register (bit n=3 of node.addr)
	if (node.addr & 0x08){
		uint8_t new_reg_value = (old_reg_value[1] & ~bitmask) | (state & bitmask);
		retVal = write_register(node.addr, REG_OUTPUT1, new_reg_value);
	} else {
		uint8_t new_reg_value = (old_reg_value[0] & ~bitmask) | (state & bitmask);
		retVal = write_register(node.addr, REG_OUTPUT0, new_reg_value);
	}

	return retVal;
}

/**
  * @brief: Read function for reading individual nodes
  * @param: node to read
  * @retval: IO_HIGH or IO_LOW
  */
uint8_t read_node(node_t node){

	// select upper or lower register (bit n=3 of node.addr)
	uint8_t register_address = (node.addr & 0x08) ? REG_INPUT1 : REG_INPUT0;

	// read IO status and compare with bitmask
	if(read_register(node.addr, register_address) & get_one_hot(node.addr)){
		return IO_HIGH;
	} else {
		return IO_LOW;
	}
}

/**
  * @brief: Configuration function for addressing individual nodes
  * @param: target node and states: IO_HIZ or IO_OE
  * @retval: operation success
  * @note: targets configuration-register of port expander
  */
_Bool configure_node(node_t node, uint8_t state){

	_Bool retVal;

	// read current register contents
	uint8_t old_reg_value[2] = {read_register(node.addr, REG_CONFIG0),
		read_register(node.addr, REG_CONFIG1)};

	// generate bitmask of tagrgeted pin
	uint8_t bitmask = get_one_hot(node.addr);

	// select upper or lower register (bit n=3 of node.addr)
	if (node.addr & 0x08){
		uint8_t new_reg_value = (old_reg_value[1] & ~bitmask) | (state & bitmask);
		retVal = write_register(node.addr, REG_CONFIG1, new_reg_value);
	} else {
		uint8_t new_reg_value = (old_reg_value[0] & ~bitmask) | (state & bitmask);
		retVal = write_register(node.addr, REG_CONFIG0, new_reg_value);
	}

	return retVal;
}

/**
  * @brief: Set given node to output-enable and low-state
  * @param: target node
  * @retval: none
  */
void node_output_low(node_t node){
	write_node(node, IO_LOW);
	configure_node(node, IO_OE);
}

/**
  * @brief: Set given node to output-enable and high-state
  * @param: target node
  * @retval: none
  */
void node_output_high(node_t node){
	write_node(node, IO_HIGH);
	configure_node(node, IO_OE);
}

/**
  * @brief: Set given node high-impedance and high (reset state)
  * @param: target node
  * @retval: none
  */
void node_release(node_t node){
	configure_node(node, IO_HIZ);
	write_node(node, IO_HIGH);
}

/**
  * @brief: Set busy-LED output
  * @param: state: LED_ON or LED_OFF
  * @retval: none
  */
void set_busy_led(int state){
	switch(state){
		case LED_ON:
			HAL_GPIO_WritePin(LD2_GPIO_Port, LD2_Pin, SET);
			break;
		case LED_OFF:
			HAL_GPIO_WritePin(LD2_GPIO_Port, LD2_Pin, RESET);
			break;
		default:
			HAL_GPIO_WritePin(LD2_GPIO_Port, LD2_Pin, RESET);
			break;
	}
}

/**
  * @brief: Set error-LED output
  * @param: state: LED_ON or LED_OFF
  * @retval: none
  */
void set_error_led(int state){
	switch(state){
		case LED_ON:
			HAL_GPIO_WritePin(LD1_GPIO_Port, LD1_Pin, SET);
			break;
		case LED_OFF:
			HAL_GPIO_WritePin(LD1_GPIO_Port, LD1_Pin, RESET);
			break;
		default:
			HAL_GPIO_WritePin(LD1_GPIO_Port, LD1_Pin, RESET);
			break;
	}
}
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

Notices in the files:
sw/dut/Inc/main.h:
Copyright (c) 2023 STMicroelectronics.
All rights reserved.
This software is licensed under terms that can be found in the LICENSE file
